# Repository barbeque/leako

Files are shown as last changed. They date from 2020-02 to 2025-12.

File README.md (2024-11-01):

The Leako logo

A ColecoVision-compatible games console that you can build yourself!

# License
The Leako project is licensed under [the Creative Commons Attribution-NonCommercial 4.0 license](https://creativecommons.org/licenses/by-nc/4.0/).

# Project Introduction
I originally developed this board in order to play some ColecoVision games that I had gotten from the flea market. This turned into several articles on my old-computer repair blog, Leaded Solder:

 - [Part 1](https://www.leadedsolder.com/2020/02/16/colecovision-diy-part-1.html), covering the impetus and design;
 - [Part 2](https://www.leadedsolder.com/2020/07/10/colecovision-diy-part-2.html), covering the assembly and debugging.
 - [Part 3](https://www.leadedsolder.com/2021/10/14/colecovision-diy-part-3.html), covering "digital" joysticks and the Hand Controller
 - [Part 4](https://www.leadedsolder.com/2021/10/26/colecovision-diy-part-4.html), partially covering "quadrature" joysticks such as the steering wheel and Roller Controller

If you enjoyed this project or if you're interested in contributing to future development, I would greatly appreciate a subscription to [the Leaded Solder Patreon](https://www.patreon.com/leadedsolder). The Patreon not only helps me afford to develop expensive projects like this one, but also includes behind-the-scenes posts and previews of upcoming articles.

# Building It Yourself
First, use a PCB fabrication shop such as JLCPCB or PCBWay to order a Gerber file. You can get those from [the Releases page](https://github.com/barbeque/leako/releases).

Stay tuned for a more involved assembly guide, but early adopters are welcome to assemble and test a board.

For the easiest build, you can install [the Interactive BOM Plugin](https://github.com/openscopeproject/InteractiveHtmlBom) and use KiCad to export it. This will give you a click-through visual BOM that makes it really easy to assemble the board. Future versions of this board will come with one of these files in the Release.

You'll want to consult the BOM PDF for the version of the Leako board you wish to assemble. The first truly "working" version was v0.6. I recommend getting [the Gerber ZIPs and BOM from the Releases page](https://github.com/barbeque/leako/releases).

Not all parts on the BOM (Bill of Materials) can be obtained new. Many components are salvaged and can be obtained from eBay or other Chinese-market surplus stores such as AliExpress. Because the sellers and availability are changing constantly, I unfortunately cannot recommend a specific vendor. I suggest ordering from multiple different sellers and building more Leakos with all the leftover parts :)

For a quicker checkout process, [I have constructed a Digi-Key "list"](https://www.digikey.ca/en/mylists/list/FZA1NMR795) which can help you add all of the "new" parts necessary quickly. 

Namely, you will need to find:
 - A TI TMS9918A/TMS9918ANL (_not_ TMS9118, TMS9119, TMS9929, or TMS9928) VDP;
 - A TI SN76489 sound chip;
 - A 27c512-compatible EPROM (a 27c256 may also work but has not been tested);
 - ColecoVision cartridge games;
 - A ColecoVision-compatible controller

Please note the Leako has, so far, only been constructed and tested in NTSC regions. A PAL version would be a very interesting conversion, but would use a chip like a TMS9919 as well as probably some other board changes.

You will also need a USB power supply and a USB-B cable. I recommend using a USB power supply capable of at least 2A - although I have only measured ~450mA max in practice, it would not be a bad idea to have some additional headroom. A lower-quality supply is also likely to introduce more noise. I have tested with two models of Anker PowerPort.

Please also note that at the time of publication, a silicon and fabrication shortage has meant that many parts (for instance, the TI TPS60403 -5V voltage inverter) have become difficult and/or more expensive to locate than when the machine was originally designed. Some have been substituted, but there are likely others.

## Tools
The ColecoVision games and console rely on the presence of a BIOS ROM. In order to program the EPROM with the BIOS, you'll need a copy of the BIOS (it can be dumped from a real ColecoVision) and an EPROM programmer such as a TL866II+.

For soldering surface-mount parts, I strongly recommend a good temperature-controlled soldering iron such as a Hakko FX-888, paste flux, and quality leaded solder from a brand like Kester or MG Chemical. You can use lead-free solder, but I haven't.

# Compatibility
If you have built your own Leako and tested it with a game that's not listed here, please submit a pull request to add it to this list.

| Game | Works? | Notes |
|---|---|---|
| Donkey Kong | Yes | |
| Zaxxon | Yes | |
| Time Pilot | Yes | |
| Carnival | Yes | |
| Frenzy | Yes | |
| Ken Uston's Black Jack / Poker | Yes | |
| Looping 	| Yes	 |	 |
| Omega Race	| Yes	 | Tested with Hand Controller |

| Peripheral | Works? | Notes |
|---|---|---|
| ColecoVision controller | Yes | |
| ADAM controller | Yes | |
| Super Action Controller | Yes | Tested with _Super Action Baseball_ only |
| Roller Controller | Partial | Tested with _Slither_ only; my controller is not working properly, even on a real ColecoVision |
| Expansion Module #2 (steering controller) | Partial | Tested with _Turbo_ only; my controller is not working properly, even on a real ColecoVision |

The latter two will be re-investigated as the controllers are tested, and hopefully this table will be updated with some better news in the future.

Please note:
 * The Leako board does not have a ColecoVision expansion connector, so it cannot work with any Expansion Modules, including the ADAM.
 * The Leako board does not have a ColecoVision power connector, so the Roller Controller will need to be powered independently using a ColecoVision power supply such as the ColUSB, or wired for a +5V source such as a USB cable.

# Known Issues
## "Always On" phenomenon
If you power the Leako off a monitor or television set that is also being used to display the Leako, it can complete the "ground" circuit from the USB jack through the composite video jack and keep the Leako turned on, bypassing the power switch entirely. In this scenario, the Leako will remain powered on, regardless of the power switch position.

To work around this problem, try powering the Leako from a different USB power source, or use a television that isolates USB ground from video ground.

Thank you to Cheshire Noir and Tom Storey for figuring this one out.

# Version History
## v0.8
More small fixes.
 * Move U20/U11 to other side of board so cartridges with extra long skirts or loose PCBs won't interfere with them.
 * Move mounting hole added in previous step to side of cartridge slot, so you don't have to use a low-profile screw head there anymore.
 * Larger pads on the 74LS574s, to ease soldering.
 * It is now much harder to hit the video filtering capacitor with the tip of a video cable.
 * Upgraded project files to KiCad 6

## v0.7
Many small fixes, mostly around reliability.
 * Correct missing junction from D3/D4 to R35 (EXT_QUAD pulldown.) Thank you to Oliver Fiero for catching this.
 * Unused logic inputs grounded to reduce power consumption.
 * Change controller ports from generic KiCad DE9 footprint to AE10968-ND
 * Change -5V charge pump because of parts shortage. Now ICL7660.
 * Controller port numbers on schematic now reflect actual logical controller ports.
 * Barrel jack 5V replaced with USB-B to broaden availability of high-quality regulated power supplies.
 * Additional mounting hole behind cartridge to reduce amount of board flex when cartridges are inserted and removed.
 * Thicker power traces.
 * Passives now labeled on board where possible, to speed assembly.

## v0.6
First working version.

# Links
 - [Console5 schematics and parts list](https://console5.com/wiki/Colecovision)
 - ChildOfCv's [better schematics](https://atariage.com/forums/topic/285656-new-colecovision-schematics/)
 - [Datasheet for LC331632M-12 SRAM](https://www.datasheet4u.com/datasheet-pdf/Sanyo/LC331632M-12/pdf.php?id=391797)
 - [Leonardo Miliani's SRAM video mod](https://www.leonardomiliani.com/en/2019/lm80c-tms9918a/)

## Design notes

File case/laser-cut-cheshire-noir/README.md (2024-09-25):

# Laser-cut case
By Cheshire Noir (thanks!)

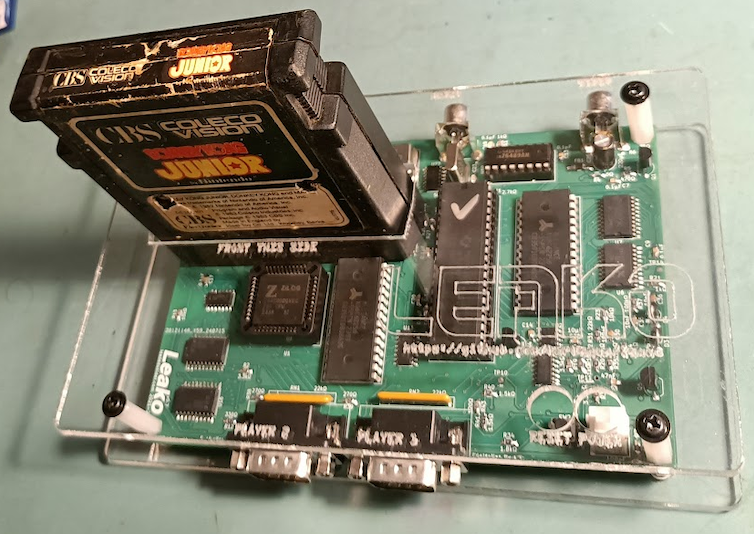
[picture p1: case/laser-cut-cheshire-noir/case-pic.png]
The case


## Other required parts
 - 5mm M3 nylon spacers
 - 20mm M3 nylon spacers

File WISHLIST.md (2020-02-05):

- [ ] Super Game Module support (32kB RAM, AY-3-8910A; remaps BIOS in memory space?)
- [ ] ADAM support (64kB RAM, ???; different decode logic for CV vs. ADAM mode?)
- [ ] Built-in flashcart BIOS with menu
- [ ] Portable variant (rearranged board) with LCD
- [ ] Backplane variant for easier testing/isolation
- [ ] Sega Genesis controller support (3 button + start instead of numpad)
- [ ] RGB output (requires TMS-9928)

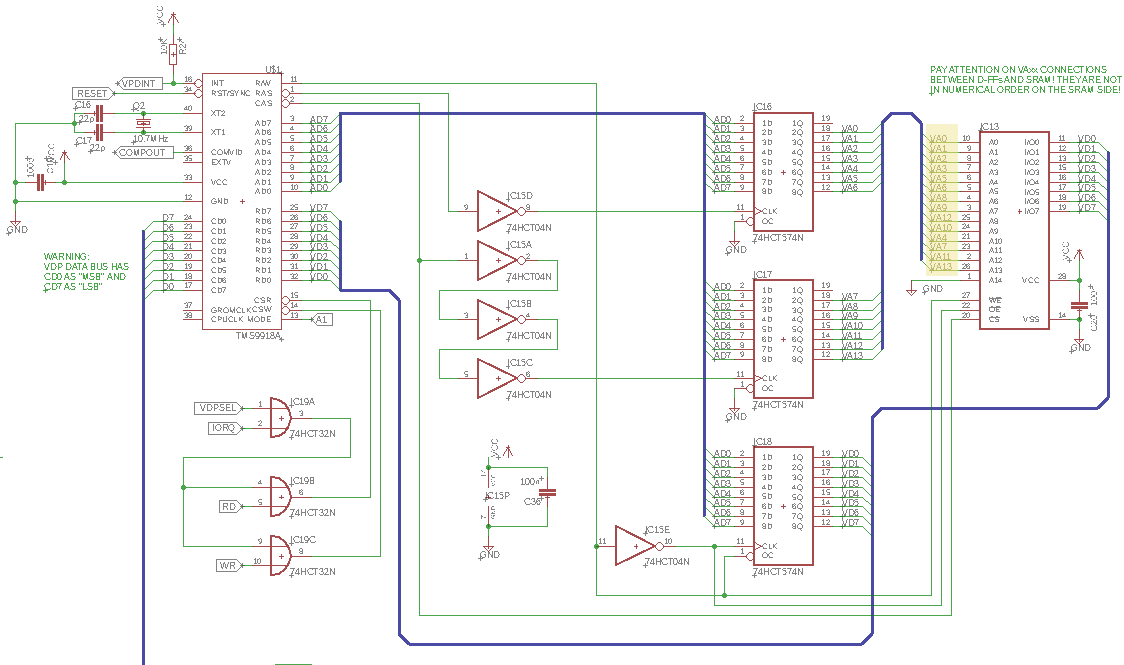
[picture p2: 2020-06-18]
References/leonardo tms9918 sram mod.png

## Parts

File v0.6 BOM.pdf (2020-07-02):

# Leako v0.6 BOM

Ref | Qnty | Value | Part | Footprint
C1, C2, C5, C6, C7, C8, C9, C13, C15, C16, C17, C18, C19, C20, C22, C24, C27, C29, C33, C34 | 20 | 0.1µF | Device:C | Capacitors_SMD:C_0805_HandSoldering
C3, C32 | 2 | 47nF | Device:C | Capacitors_SMD:C_0805_HandSoldering
C4 | 1 | 0.1µF | Device:CP1_Small | Capacitors_SMD:C_0805_HandSoldering
C10, C11 | 2 | 0.1µF | Device:C_Small | Capacitors_SMD:C_0805_HandSoldering
C12 | 1 | 22µF | Device:CP | Capacitors_ThroughHole:CP_Radial_D5.0mm_P2.50mm
C21, C39, C40, C41 | 4 | 1µF | Device:C | Capacitors_SMD:C_0805_HandSoldering
C23, C26 | 2 | 56pF | Device:C_Small | Capacitors_SMD:C_0805_HandSoldering
C25 | 1 | 220µF | Device:CP1_Small | Capacitors_ThroughHole:CP_Radial_D6.3mm_P2.50mm
C30, C31 | 2 | 100pF | Device:C | Capacitors_SMD:C_0805_HandSoldering
C35, C36, C37, C38 | 4 | 10nF | Device:C | Capacitors_SMD:C_0805_HandSoldering
D1 | 1 | LED | Device:LED | LEDs:LED_D3.0mm
D2 | 1 | 50V 2A | Device:D_Schottky | Diodes_ThroughHole:D_DO-15_P10.16mm_Horizontal
D3, D4 | 2 | 1N4001 | Diode:1N4001 | Diodes_ThroughHole:D_DO-41_SOD81_P2.54mm_Vertical_AnodeUp
F2 | 1 | 2A | Device:Fuse_Small | 0251002.MRT1L:0251002.MRT1L
FB1 | 1 | Bead | Device:Ferrite_Bead_Small | Choke_SMD:Choke_SMD_1206_Handsoldering
J1 | 1 | Cartridge Slot | Connector_Generic:Conn_02x15_Odd_Even | LeakyChips:Sullins_Cart_Slot
J2 | 1 | Composite video | RCJ-017:RCJ-017 | Jacks:CUI_RCJ-017
J3 | 1 | PJ-102A | PJ-102A:PJ-102A | Jacks:CUI_PJ-102A
J4 | 1 | RCJ-017 | RCJ-017:RCJ-017 | Jacks:CUI_RCJ-017
J5 | 1 | Controller Port 1 | Connector:DB9_Male | Connector_Dsub:DSUB-9_Male_Horizontal_P2.77x2.84mm_EdgePinOffset4.94mm_Housed_MountingHolesOffset7
J6 | 1 | Controller Port 2 | Connector:DB9_Male | Connector_Dsub:DSUB-9_Male_Horizontal_P2.77x2.84mm_EdgePinOffset4.94mm_Housed_MountingHolesOffset7
Q1 | 1 | 2n4401 | Device:Q_NPN_EBC | TO_SOT_Packages_THT:TO-92_Inline_Wide
Q2 | 1 | Q_NJFET_GSD | Device:Q_NJFET_GSD | TO_SOT_Packages_SMD:SOT-23_Handsoldering
Q4, Q5 | 2 | 2N3904 | Transistor_BJT:2N3904 | TO_SOT_Packages_THT:TO-92_Inline_Wide
R1, | 5 | 1kΩ | Device:R_Small_US | Resistors_SMD:R_0805_HandSoldering

R11, R18, R21, R28

R2, R3, R9, R10, R14, R19, R44 | 7 | 3.3kΩ | Device:R_Small_US | Resistors_SMD:R_0805_HandSoldering
R4 | 1 | 0Ω | Device:R_Small_US | Resistors_SMD:R_0805_HandSoldering
R5 | 1 | 470Ω | Device:R_Small_US | Resistors_SMD:R_0805_HandSoldering
R6 | 1 | 75Ω | Device:R_Small_US | Resistors_SMD:R_0805_HandSoldering
R7 | 1 | 150Ω | Device:R_Small_US | Resistors_SMD:R_0805_HandSoldering
R12 | 1 | 330Ω | Device:R_Small_US | Resistors_SMD:R_0805_HandSoldering
R13, R23, R24 | 3 | 10kΩ | Device:R_Small_US | Resistors_SMD:R_0805_HandSoldering
R15 | 1 | 4.7kΩ | Device:R_Small_US | Resistors_SMD:R_0805_HandSoldering
R16 | 1 | 91kΩ | Device:R_Small_US | Resistors_SMD:R_0805_HandSoldering
R17 | 1 | 1MΩ | Device:R_Small_US | Resistors_SMD:R_0805_HandSoldering
R20, R31, R32 | 3 | 22kΩ | Device:R_Small_US | Resistors_SMD:R_0805_HandSoldering
R27 | 1 | 47Ω | Device:R_Small_US | Resistors_SMD:R_0805_HandSoldering
R33, R34 | 2 | 1.8kΩ | Device:R_Small_US | Resistors_SMD:R_0805_HandSoldering
R35, R40, R41 | 3 | 1.5kΩ | Device:R_Small_US | Resistors_SMD:R_0805_HandSoldering
R36, R37 | 2 | 100kΩ | Device:R_Small_US | Resistors_SMD:R_0805_HandSoldering
R38, R39 | 2 | 270Ω | Device:R_Small_US | Resistors_SMD:R_0805_HandSoldering
R42, R43 | 2 | 120Ω | Device:R_Small_US | Resistors_SMD:R_0805_HandSoldering
RN1, RN2 | 2 | 22kΩ | Device:R_Network07_US | Resistors_ThroughHole:R_Array_SIP8
SW1 | 1 | Power Toggle | Switch:SW_Push | LeakyChips:PVA1_Switch
SW2 | 1 | Reset | Switch:SW_Push | Buttons_Switches_ThroughHole:SW_PUSH_6mm
U1 | 1 | PLCCZ80 | LeadedSolder:PLCCZ80 | Sockets:PLCC44
U3 | 1 | BIOS ROM 27C256 | Memory_EPROM:27C256 | Housings_DIP:DIP-28_W15.24mm_Socket_LongPads
U4 | 1 | 74HCT04 | 74xx:74HCT04 | Housings_SOIC:SOIC-14_3.9x8.7mm_Pitch1.27mm
U5 | 1 | TMS9918A | LeakoChips:TMS9918A | Housings_DIP:DIP-40_W15.24mm_Socket_LongPads
U6, U7, U8 | 3 | 74HCT574 | 74xx:74LS574 | Housings_SOIC:SOIC-20W_7.5x12.8mm_Pitch1.27mm
U10 | 1 | SN76489AN | LeakoChips:SN76489AN | Housings_DIP:DIP-16_W7.62mm_Socket_LongPads
U11 | 1 | 74LS04 | 74xx:74LS04 | Housings_SOIC:SOIC-14_3.9x8.7mm_Pitch1.27mm
U12 | 1 | 74LS138 (Mem. Mapped) | 74xx:74LS138 | Housings_SOIC:SOIC-16_3.9x9.9mm_Pitch1.27mm
U13 | 1 | 74LS138 (I/O) | 74xx:74LS138 | Housings_SOIC:SOIC-16_3.9x9.9mm_Pitch1.27mm
U14 | 1 | 74LS02 | 74xx:74LS02 | Housings_SOIC:SOIC-14_3.9x8.7mm_Pitch1.27mm
U15 | 1 | Controller 1 | 74xx_IEEE:74LS541 | Housings_SOIC:SOIC-20W_7.5x12.8mm_Pitch1.27mm
U16 | 1 | Controller 2 | 74xx_IEEE:74LS541 | Housings_SOIC:SOIC-20W_7.5x12.8mm_Pitch1.27mm
U17, U18 | 2 | 74LS05 | 74xx:74LS05 | Housings_SOIC:SOIC-14_3.9x8.7mm_Pitch1.27mm
U20, U22 | 2 | 74LS74 | 74xx:74LS74 | Housings_SOIC:SOIC-14_3.9x8.7mm_Pitch1.27mm
U23 | 1 | 74HCT00 | 74xx:74HCT00 | Housings_SOIC:SOIC-14_3.9x8.7mm_Pitch1.27mm
U24 | 1 | TPS60403DBVR | TPS60403DBVR:TPS60403DBVR | TO_SOT_Packages_SMD:SOT-23-5_HandSoldering
U100, | 2 | AS6C62256-DIP | AS6C62256:AS6C62256-DIP | Housings_DIP:DIP-28_W15.24mm_Socket_LongPads

U101

X1 | 1 | 14.31818MHz | Oscillator:CXO_DIP8 | Oscillators:Oscillator_DIP-8_LargePads
Y1 | 1 | 10.738635MHZ | Device:Crystal | Crystals:Crystal_HC49-U_Vertical

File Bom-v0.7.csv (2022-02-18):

Customer Reference | Component Name | Value | Footprint | Part Number | Quantity | Description
C1, C2, C4, C5, C6, C7, C8, C9, C10, C11, C13, C15, C16, C17, C18, C19, C20, C22, C24, C27, C29, C33, C34 | C | 0.1µF | Capacitors_SMD:C_0805_HandSoldering | 1276-1099-1-ND | 23 | Unpolarized capacitor
C3, C32 | C | 47nF | Capacitors_SMD:C_0805_HandSoldering | 732-8059-1-ND | 2 | Unpolarized capacitor
C12 | CP | 22µF | Capacitors_ThroughHole:CP_Radial_D5.0mm_P2.50mm | 493-1037-ND | 1 | Polarized capacitor
C14, C28 | C_Small | 10µF | Capacitor_SMD:C_0805_2012Metric_Pad1.15x1.40mm_HandSolder | 1276-1298-1-ND | 2 | Unpolarized capacitor, small symbol
C21 | C | 1µF | Capacitors_SMD:C_0805_HandSoldering | 1276-2926-1-ND | 1 | Unpolarized capacitor
C23, C26 | C_Small | 56pF | Capacitors_SMD:C_0805_HandSoldering | 732-7817-1-ND | 2 | Unpolarized capacitor, small symbol
C25 | CP1_Small | 220µF | Capacitors_ThroughHole:CP_Radial_D6.3mm_P2.50mm | 493-15121-ND | 1 | Polarized capacitor, small US symbol
C30, C31 | C | 100pF | Capacitors_SMD:C_0805_HandSoldering | 732-12161-1-ND | 2 | Unpolarized capacitor
C35, C36, C37, C38 | C | 10nF | Capacitors_SMD:C_0805_HandSoldering | 399-C0805X103K1RAC3316CT-ND | 4 | Unpolarized capacitor
D1 | LED | LED | LEDs:LED_D3.0mm | 1497-1022-ND | 1 | Light emitting diode
D3, D4 | 1N4001 | 1N4001 | Diodes_ThroughHole:D_DO-41_SOD81_P2.54mm_Vertical_AnodeUp | 641-1310-1-ND | 2 | 50V 1A General Purpose Rectifier Diode, DO-41
F2 | Fuse_Small | 2A | 0251002.MRT1L:0251002.MRT1L | F3171CT-ND | 1 | Fuse, small symbol
FB1 | Ferrite_Bead_Small | Bead | Choke_SMD:Choke_SMD_1206_Handsoldering | 283-MFBW1V3216-310-RCT-ND | 1 | Ferrite bead, small symbol
J1 | Conn_02x15_Odd_Even | Cartridge Slot | LeakyChips:Sullins_Cart_Slot | S3305-ND | 1 | Generic connector, double row, 02x15, odd/even pin numbering scheme (row 1 odd numbers, row 2 even numbers), script generated (kicad-library-utils/schlib/autogen/connector/)
J2 | RCJ-017 | Composite video | Jacks:CUI_RCJ-017 | CP-1403-ND‎ | 1
J3 | USB-B1HSB6 | USB-B1HSB6 | OST_USB-B1HSB6 | ED2982-ND | 1
J4 | RCJ-017 | RCJ-013 | Jacks:CUI_RCJ-017 | CP-1402-ND‎ | 1
J5 | DB9_Male | Controller Port 2 | Jacks:A-DS 09 A-KG-T2S | AE10968-ND | 1 | 9-pin male D-SUB connector
J6 | DB9_Male | Controller Port 1 | Jacks:A-DS 09 A-KG-T2S | AE10968-ND | 1 | 9-pin male D-SUB connector
Q1 | Q_NPN_EBC | 2n4401 | TO_SOT_Packages_THT:TO-92_Inline_Wide | 2N4401TFCT-ND | 1 | NPN transistor, emitter/base/collector
Q2 | Q_NJFET_GSD | Q_NJFET_GSD | TO_SOT_Packages_SMD:SOT-23_Handsoldering | DMN6075S-7DICT-ND | 1 | N-JFET transistor, gate/source/drain
Q4, Q5 | 2N3904 | 2N3904 | TO_SOT_Packages_THT:TO-92_Inline_Wide | 2N3904TAFSCT-ND | 2 | 0.2A Ic, 40V Vce, Small Signal NPN Transistor, TO-92
R1 | R_Small_US | 2.7kΩ | Resistors_SMD:R_0805_HandSoldering | RMCF0805JT2K70CT-ND | 1 | Resistor, small US symbol
R2, R3, R9, R10, R14, R19, R44 | R_Small_US | 3.3kΩ | Resistors_SMD:R_0805_HandSoldering | RMCF0805JT3K30CT-ND | 7 | Resistor, small US symbol
R4 | R_Small_US | 0Ω | Resistors_SMD:R_0805_HandSoldering | RMCF0805ZT0R00CT-ND | 1 | Resistor, small US symbol
R5 | R_Small_US | 470Ω | Resistors_SMD:R_0805_HandSoldering | RMCF0805JT470RCT-ND | 1 | Resistor, small US symbol
R6 | R_Small_US | 75Ω | Resistors_SMD:R_0805_HandSoldering | RMCF0805JT75R0CT-ND | 1 | Resistor, small US symbol
R7 | R_Small_US | 150Ω | Resistors_SMD:R_0805_HandSoldering | RMCF0805JT150RCT-ND | 1 | Resistor, small US symbol
R11, R18, R21, R28 | R_Small_US | 1kΩ | Resistors_SMD:R_0805_HandSoldering | RMCF0805FT1K00CT-ND | 4 | Resistor, small US symbol
R12 | R_Small_US | 330Ω | Resistors_SMD:R_0805_HandSoldering | RMCF0805JT330RCT-ND | 1 | Resistor, small US symbol
R13, R23, R24 | R_Small_US | 10kΩ | Resistors_SMD:R_0805_HandSoldering | RMCF0805JT10K0CT-ND | 3 | Resistor, small US symbol
R15 | R_Small_US | 4.7kΩ | Resistors_SMD:R_0805_HandSoldering | RMCF0805JT4K70CT-ND | 1 | Resistor, small US symbol
R16 | R_Small_US | 91kΩ | Resistors_SMD:R_0805_HandSoldering | RMCF0805JT91K0CT-ND | 1 | Resistor, small US symbol
R17 | R_Small_US | 1MΩ | Resistors_SMD:R_0805_HandSoldering | RMCF0805JT1M00CT-ND | 1 | Resistor, small US symbol
R20, R31, R32 | R_Small_US | 22kΩ | Resistors_SMD:R_0805_HandSoldering | RMCF0805JT22K0CT-ND | 3 | Resistor, small US symbol
R27 | R_Small_US | 47Ω | Resistors_SMD:R_0805_HandSoldering | RMCF0805JT47R0CT-ND | 1 | Resistor, small US symbol
R33, R34 | R_Small_US | 1.8kΩ | Resistors_SMD:R_0805_HandSoldering | RMCF0805JT1K80CT-ND | 2 | Resistor, small US symbol
R35, R40, R41 | R_Small_US | 1.5kΩ | Resistors_SMD:R_0805_HandSoldering | RMCF0805JT1K50CT-ND | 3 | Resistor, small US symbol
R36, R37 | R_Small_US | 100kΩ | Resistors_SMD:R_0805_HandSoldering | RMCF0805JT100KCT-ND | 2 | Resistor, small US symbol
R38, R39 | R_Small_US | 270Ω | Resistors_SMD:R_0805_HandSoldering | RMCF0805JT270RCT-ND | 2 | Resistor, small US symbol
R42, R43 | R_Small_US | 120Ω | Resistors_SMD:R_0805_HandSoldering | RMCF0805JT120RCT-ND | 2 | Resistor, small US symbol
RN1, RN2 | R_Network07_US | 22kΩ | Resistors_ThroughHole:R_Array_SIP8 | 4608X-1-223LF-ND | 2 | 7 resistor network, star topology, bussed resistors, small US symbol
SW1 | SW_Push | Power Toggle | LeakyChips:PVA1_Switch | 401-1132-ND | 1 | Push button switch, generic, two pins
SW2 | SW_Push | Reset | Buttons_Switches_ThroughHole:SW_PUSH_6mm | 679-2428-ND | 1 | Push button switch, generic, two pins
TP2, TP3, TP11 | TestPoint | TestPoint | Measurement_Points:Measurement_Point_Round-TH_Small |  | 3 | test point
TP10 | TestPoint | -5V | Measurement_Points:Measurement_Point_Round-SMD-Pad_Small |  | 1 | test point
TP14 | TestPoint | TestPoint | Measurement_Points:Measurement_Point_Round-SMD-Pad_Small |  | 1 | test point
U1 | PLCCZ80 | PLCCZ80 | Sockets:PLCC44 | 2057-PLCC-44-AT-ND | 1 | The PLCC variant of the Zilog Z80
U1 | PLCCZ80 | PLCCZ80 | Sockets:PLCC44 | 269-3899-ND | 1 | The PLCC variant of the Zilog Z80
U2 | ICL7660 | ICL7660 | Package_SO:SOIC-8_3.9x4.9mm_P1.27mm | ICL7660CSA+TCT-ND | 1 | Switched-Capacitor Voltage Converter, 1.5V to 10.0V operating supply voltage, 10mA with a 0.5V output drop, SO-8/DIP-8/µMAX-8/TO-99
U3 | 27C256 | BIOS ROM 27C256 | Housings_DIP:DIP-28_W15.24mm_Socket_LongPads | 2057-ICS-628-T-ND | 1 | OTP EPROM 256 KiBit
U4, U11 | 74LS04 | 74HCT04 | Housings_SOIC:SOIC-14_3.9x8.7mm_Pitch1.27mm | 296-31832-1-ND | 2 | Hex Inverter
U5 | TMS9918A | TMS9918A | Housings_DIP:DIP-40_W15.24mm_Socket_LongPads | ED3048-5-ND | 1
U6, U7, U8 | 74LS574 | 74HCT574 | Housings_SOIC:SOIC-20W_7.5x12.8mm_Pitch1.27mm | 1727-2856-1-ND | 3 | 8-bit Register, 3-state outputs
U10 | SN76489AN | SN76489AN | Housings_DIP:DIP-16_W7.62mm_Socket_LongPads | AE9992-ND | 1
U12 | 74LS138 | 74LS138 (Mem. Mapped) | Housings_SOIC:SOIC-16_3.9x9.9mm_Pitch1.27mm | 296-14883-2-ND | 1 | Decoder 3 to 8 active low outputs
U13 | 74LS138 | 74LS138 (I/O) | Housings_SOIC:SOIC-16_3.9x9.9mm_Pitch1.27mm | 296-14883-2-ND | 1 | Decoder 3 to 8 active low outputs
U14 | 74LS02 | 74LS02 | Housings_SOIC:SOIC-14_3.9x8.7mm_Pitch1.27mm | 296-14874-1-ND | 1 | quad 2-input NOR gate
U15 | 74LS541 | 74LS541 (Ctrl. 2) | Package_SO:SOIC-20W_7.5x12.8mm_P1.27mm | 296-14870-1-ND | 1 | 8-bit Buffer/Line Driver 3-state outputs
U16 | 74LS541 | 74LS541 (Ctrl. 1) | Package_SO:SOIC-20W_7.5x12.8mm_P1.27mm | 296-14870-1-ND | 1 | 8-bit Buffer/Line Driver 3-state outputs
U17, U18 | 74LS05 | 74LS05 | Housings_SOIC:SOIC-14_3.9x8.7mm_Pitch1.27mm | 296-1630-1-ND | 2 | Inverter Open Collect
U20, U22 | 74LS74 | 74LS74 | Housings_SOIC:SOIC-14_3.9x8.7mm_Pitch1.27mm | 296-14899-1-ND | 2 | Dual D Flip-flop, Set & Reset
U23 | 74HCT00 | 74HCT00 | Housings_SOIC:SOIC-14_3.9x8.7mm_Pitch1.27mm | 296-14542-1-ND | 1 | quad 2-input NAND gate
U100, U101 | AS6C62256-DIP | AS6C62256-DIP | Housings_DIP:DIP-28_W15.24mm_Socket_LongPads | 1450-1033-ND | 2
X1 | CXO_DIP8 | 14.31818MHz | Oscillators:Oscillator_DIP-8_LargePads | 535-9170-5-ND | 1 | Crystal Clock Oscillator, DIP8-style metal package
Y1 | Crystal | 10.738635MHZ | Crystals:Crystal_HC49-U_Vertical | CTX1443-ND | 1 | Two pin crystal

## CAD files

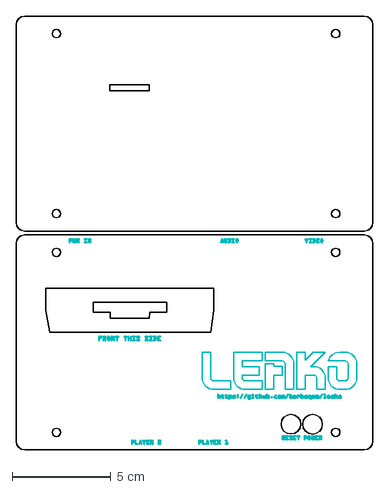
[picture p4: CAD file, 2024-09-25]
case/laser-cut-cheshire-noir/LeakoCase.dxf
18.1 x 22.0 cm

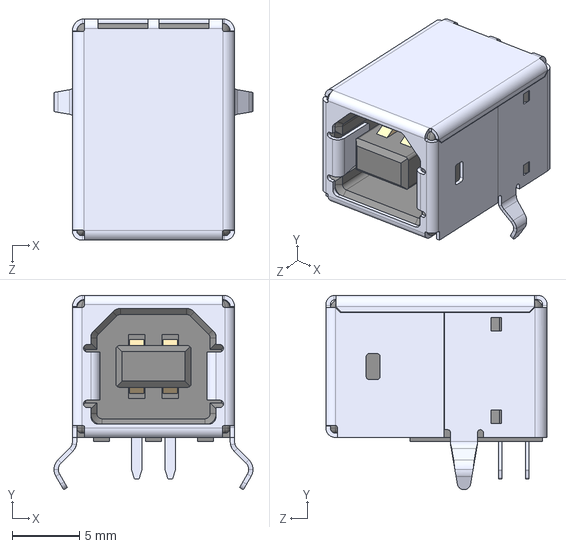
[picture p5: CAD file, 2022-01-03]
USB-B1HSB6/USB-B1HSB6.step
14.8 x 14.5 x 16.5 mm

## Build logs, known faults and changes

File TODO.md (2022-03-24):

- [x] figure out if i can use the LC331632M-12 (32k words * 16 bits) sram left over from the x'eye project - should work
- [x] figure out what the _other_ RAM was from the x'eye project - was it DRAM?
- [x] set up the SRAM-adapter for the TMS-9918 from the PDF - it's simple
- [x] figure out if I can use any of the ROMs i already have - yes, a 27c256 is more than enough
- [x] how does the original decode logic work with so few chips?
- [x] can i use one sanyo 16-bit ram for both the vdp and z80 since it has individual byte enables? NO
- [x] check the footprint against a real TMS9918 (print it out sooner rather than later)
- [x] can I use a knockoff U2413 as an AY-3-8910 to save some board room? are they that deeply compatible? i guess i already own an AY-3-8910. NEVER MIND IT'S AN SN76489 - already on order
- [x] video amp? used the one from the PDF
- [x] audio amp? is this too much gain? don't need one at all probably
- [x] reset circuit
- [x] cpu clock circuit ?????????????????? good enough for now?
- [x] how is the TMS clocked?
- [x] do i need to reverse a7..a0 for the TMS, or is that for data, or not at all?
- [x] what does RD in the SRAM-as-VRAM schematic do? they wouldn't have an extra inverter stage for nothing.
- [x] figure out memory decode
- [x] figure out IO decode
- [x] figure out cart decode (a subset of memory decode - bank switching)
- [x] what even are controllers?
- [x] add a bios rom
- [x] put in the keep-out zone for the cartridge slot (81mm x 40mm)
- [x] ram wraparound?
- [x] BIOS: what is up with the separate CE and OE in the original schematic (CE from A11?) Figure it out!!!
- [x] Expansion stubs (EXT_DEC_STUB, EXT_IO_STUB) need pullups or they'll fuck up
- [x] (CRITICAL) what is up with the -5V on the controller schematic?
- [x] fet to protect the power switch?
- [x] rca jacks around the right way?
- [x] why are the two 541s on the controller featuring different data bus pinouts?
- [x] map out the 541s
- [x] find some board spacers or a project case to lift this thing off a desk now that it's two sided
- [x] power U14, the ugly NOR that was used for the RAM
- [x] break out the remainder of the pins so i can use them as an inverter if need be
- [x] is it OK to tie CPU reset and VDP reset together? it is not
- [x] U21 feels unnecessary, we can probably drop it if we have leftover room on U14 in the end
- [x] find a replacement for the 7.15909MHz crystal (figure out how to divide a 14.31818)
- [x] you know what, can i just axe this entire clock section and use a 14mhz oscillator chip
- [x] replace the n/o jumpers with smd ones
- [x] size the power supply; can i get by with a 5V 2A switcher or will the voltage drop ruin it
- [x] power regulation - should i still have it if i have a 5V 2A switching supply?
- [x] replace the inline diode with a shunt to ground - rearrange the diode and fuse
- [x] is the SMD polyfuse on the load too small? yes, it's gone
- [x] weird flipflop-y section of the controller area with -5v
- [x] U21 (74hc04) seems not well used, lots of empty pins there
- [ ] U22 (flipflop) not well used either
- [ ] U18 (74ls05) is only half used
- [x] CRITICAL: undo the 100pF that i converted to 0.1uF on the real board (C26, C30, C31)
- [x] rotate the power switch
- [x] print out a bom for the v0.2 tag
- [x] abandon sanyo psram for 62256
# V0.7
- [ ] jumpers to potentially enable high address pins in ram (shh!)
- [ ] jumper to bypass capacitor on composite output
- [ ] jumper to switch -5V super pulldown to ground
- [x] controller port numbers flipped
- [x] unused inputs of u17 (ls05) should be grounded
- [x] unused inputs of u11 (ls04) should be grounded
- [ ] u17 and u18 should probably be merged, both are ls05s and barely used
- [ ] can u11 and u17 be merged and u11 dropped?
- [x] TI -5v regulator no longer available, use ICL7220?
- [x] bracing hole near cartridge
- [ ] ~~use the footprint of the de9 connector that i have, so it can be bolted (AMPHENOL 617-A009P-AJ121)~~
- [x] change the BOM to use a better de9 connector, possibly the one the footprint is based on (maybe AE10968-ND?)
- [x] convert power jack to USB
- [x] finish "making visible" all the hidden cap/resistor values
- [x] nice rounded edge on PCB (safety first)
# V0.8
- [x] move the mounting hole so it doesn't interfere with the cart shell when cart is loaded and screw is installed
- [ ] is the 10.7...mhz crystal making better video with 33pF or 56pF?
- [x] make 574s easier to place/solder with bigger pads

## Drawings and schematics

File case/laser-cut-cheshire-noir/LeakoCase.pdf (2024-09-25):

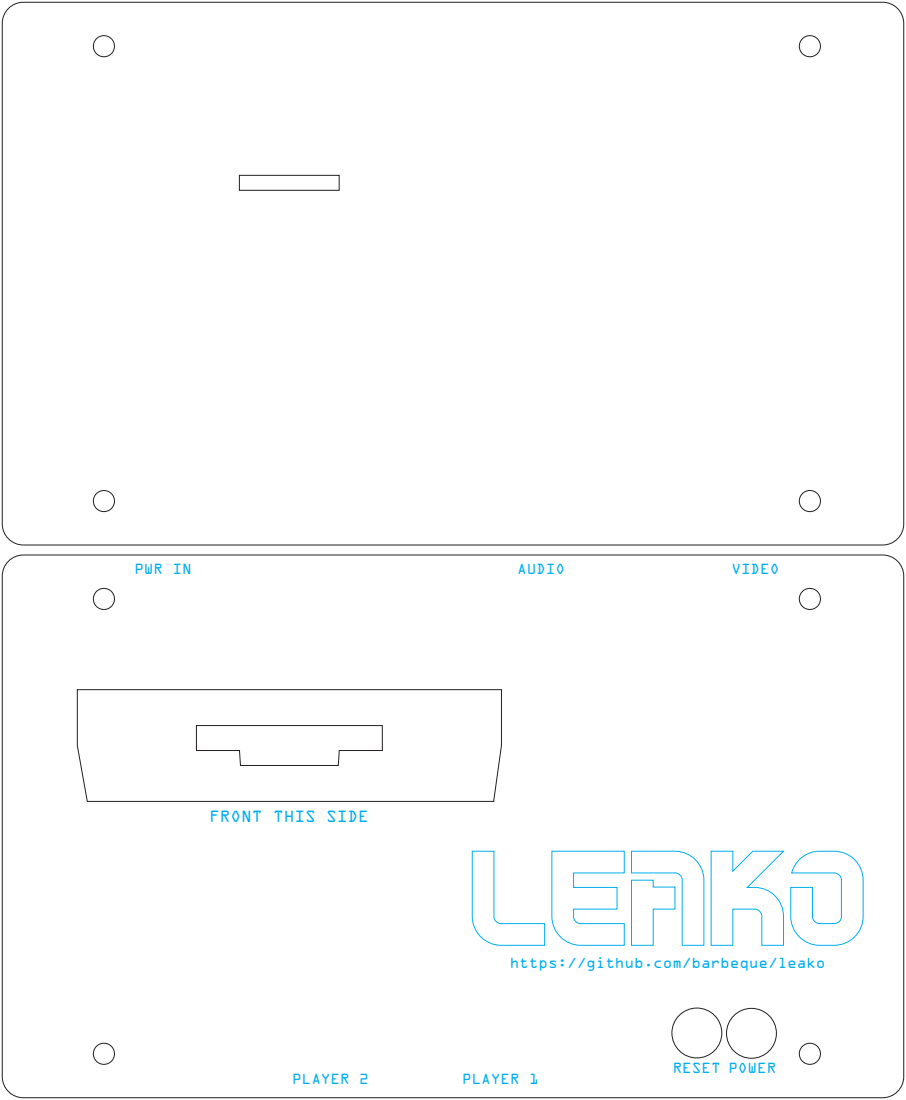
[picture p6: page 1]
RESET POWER; PWR IN; AUDIO; VIDEO; PLAYER 2; PLAYER 1

FRONT THIS SIDE

https://github.com/barbeque/leako

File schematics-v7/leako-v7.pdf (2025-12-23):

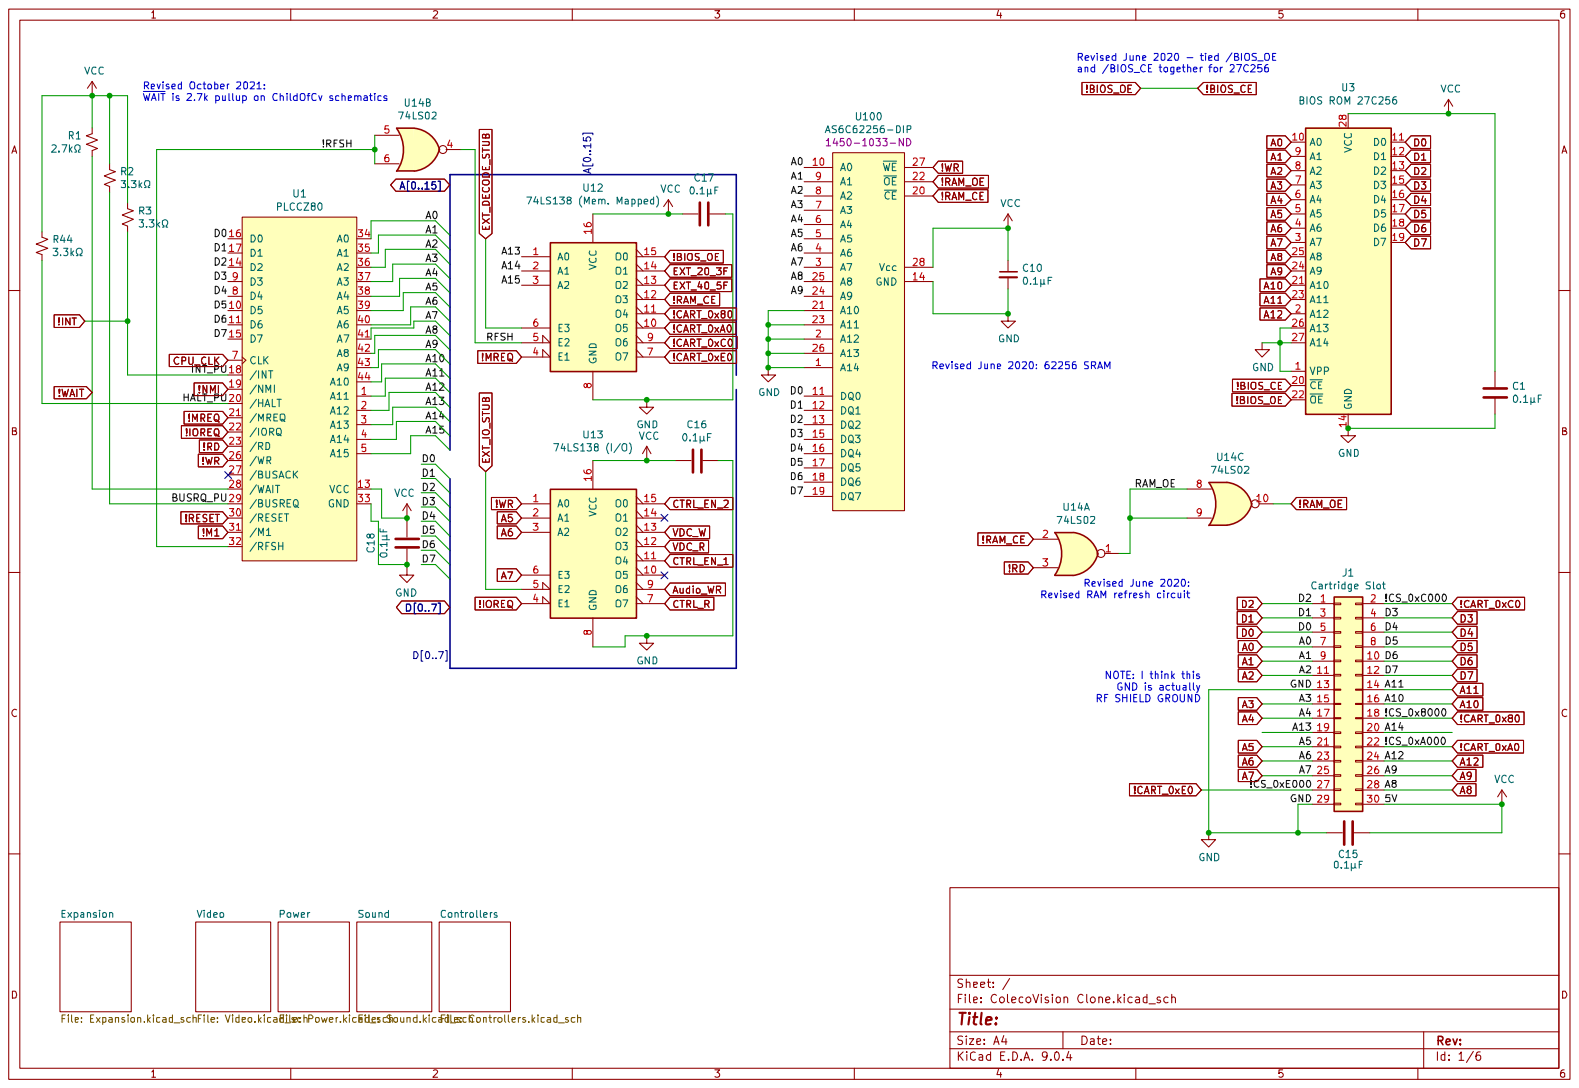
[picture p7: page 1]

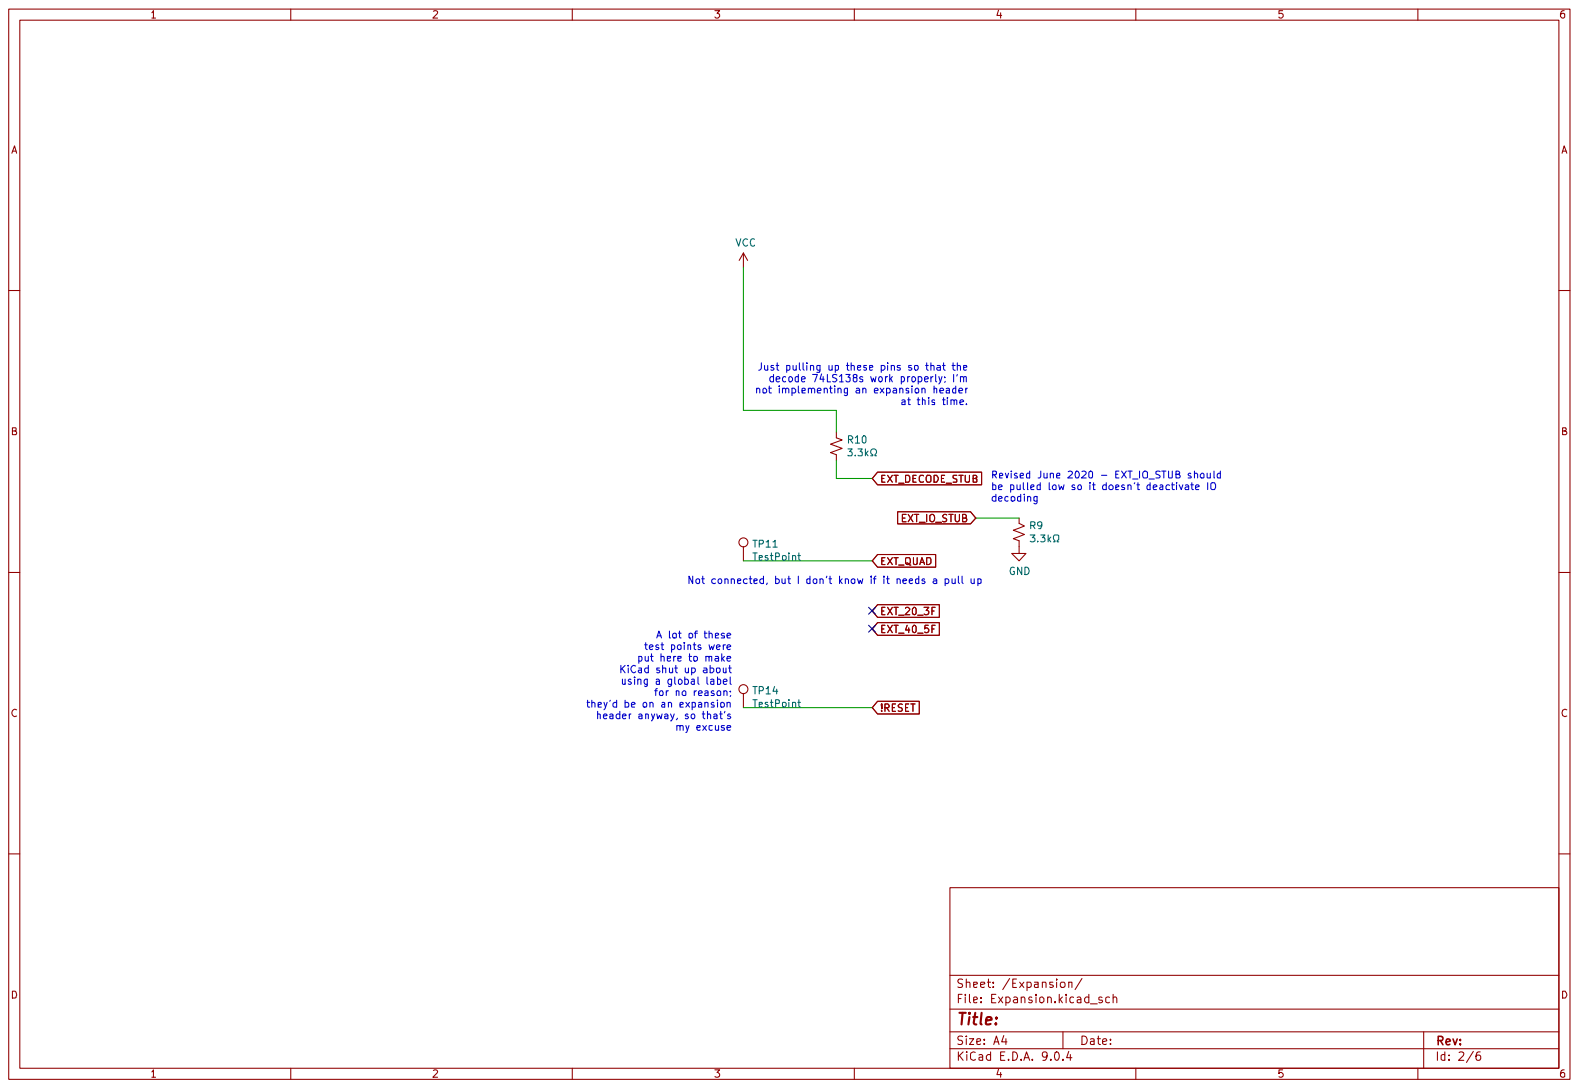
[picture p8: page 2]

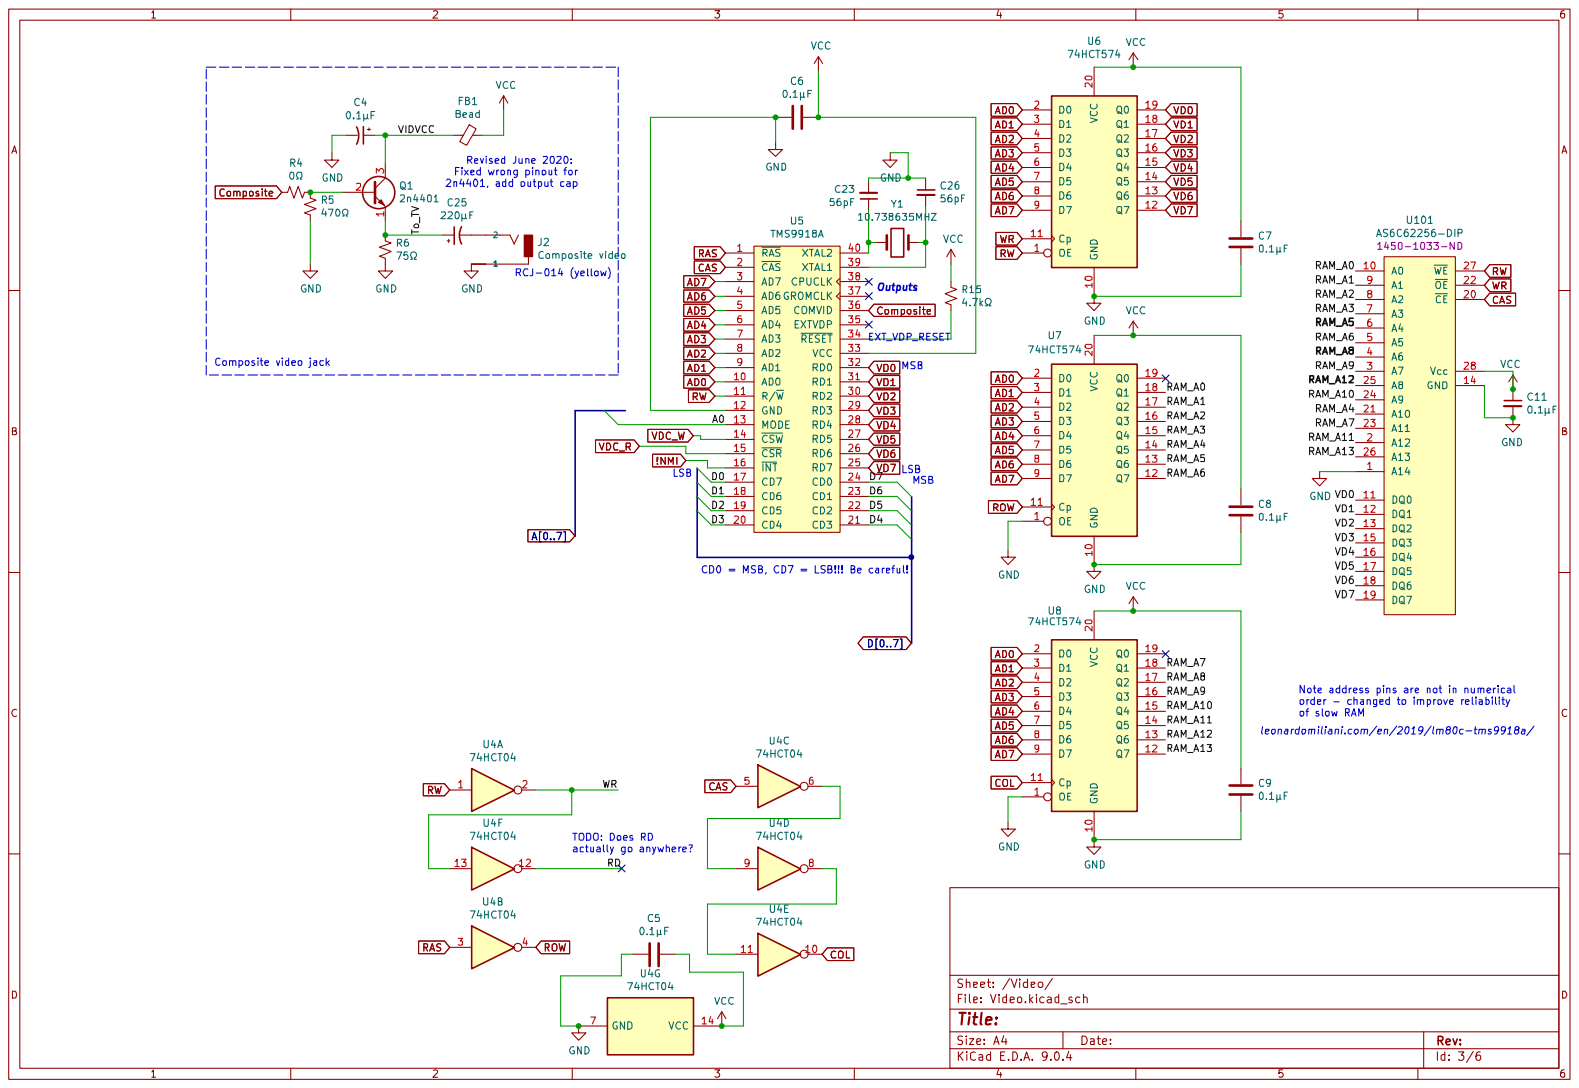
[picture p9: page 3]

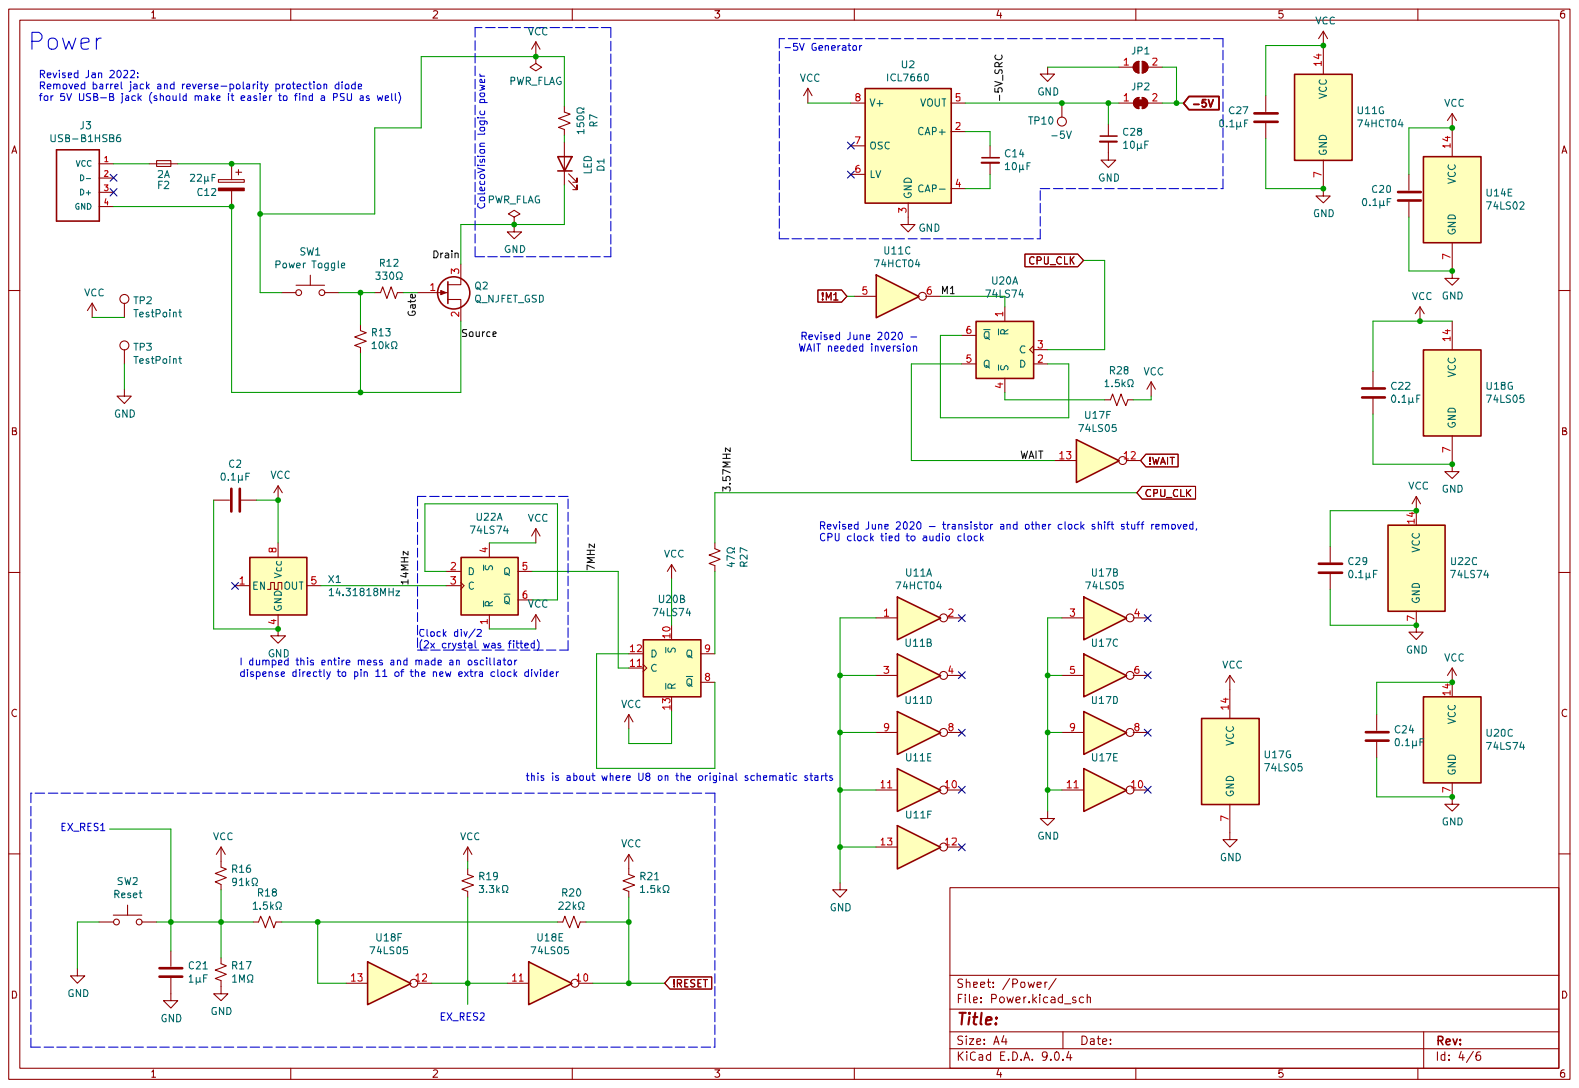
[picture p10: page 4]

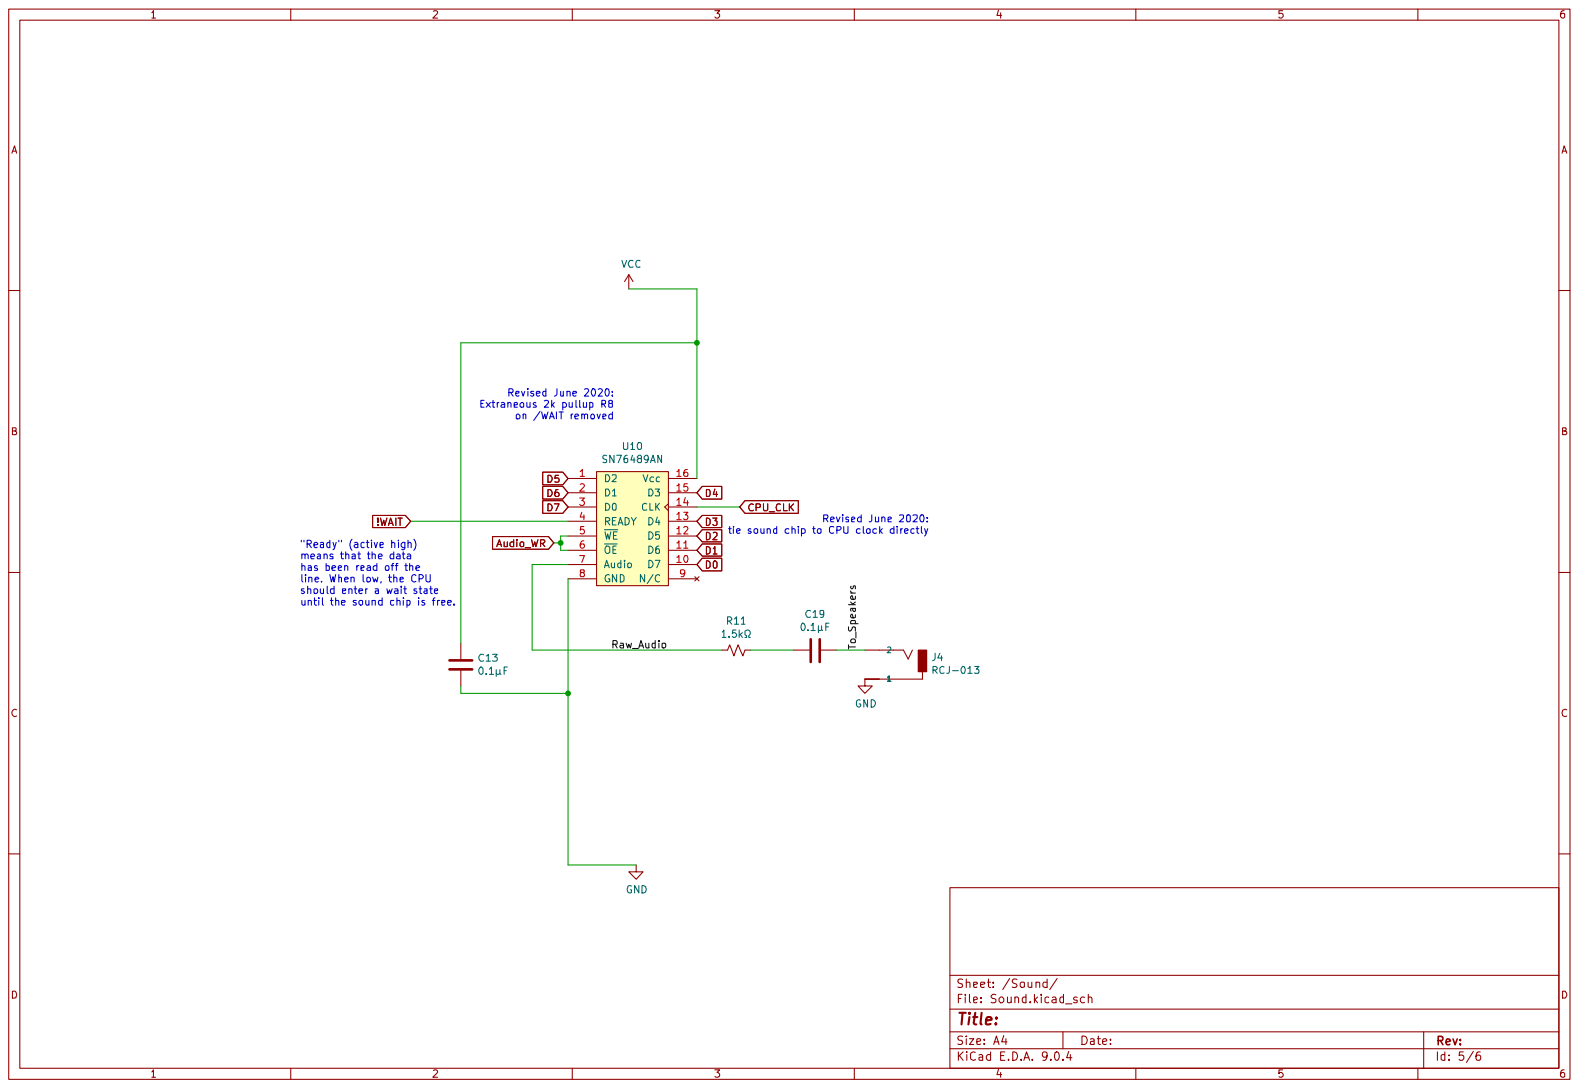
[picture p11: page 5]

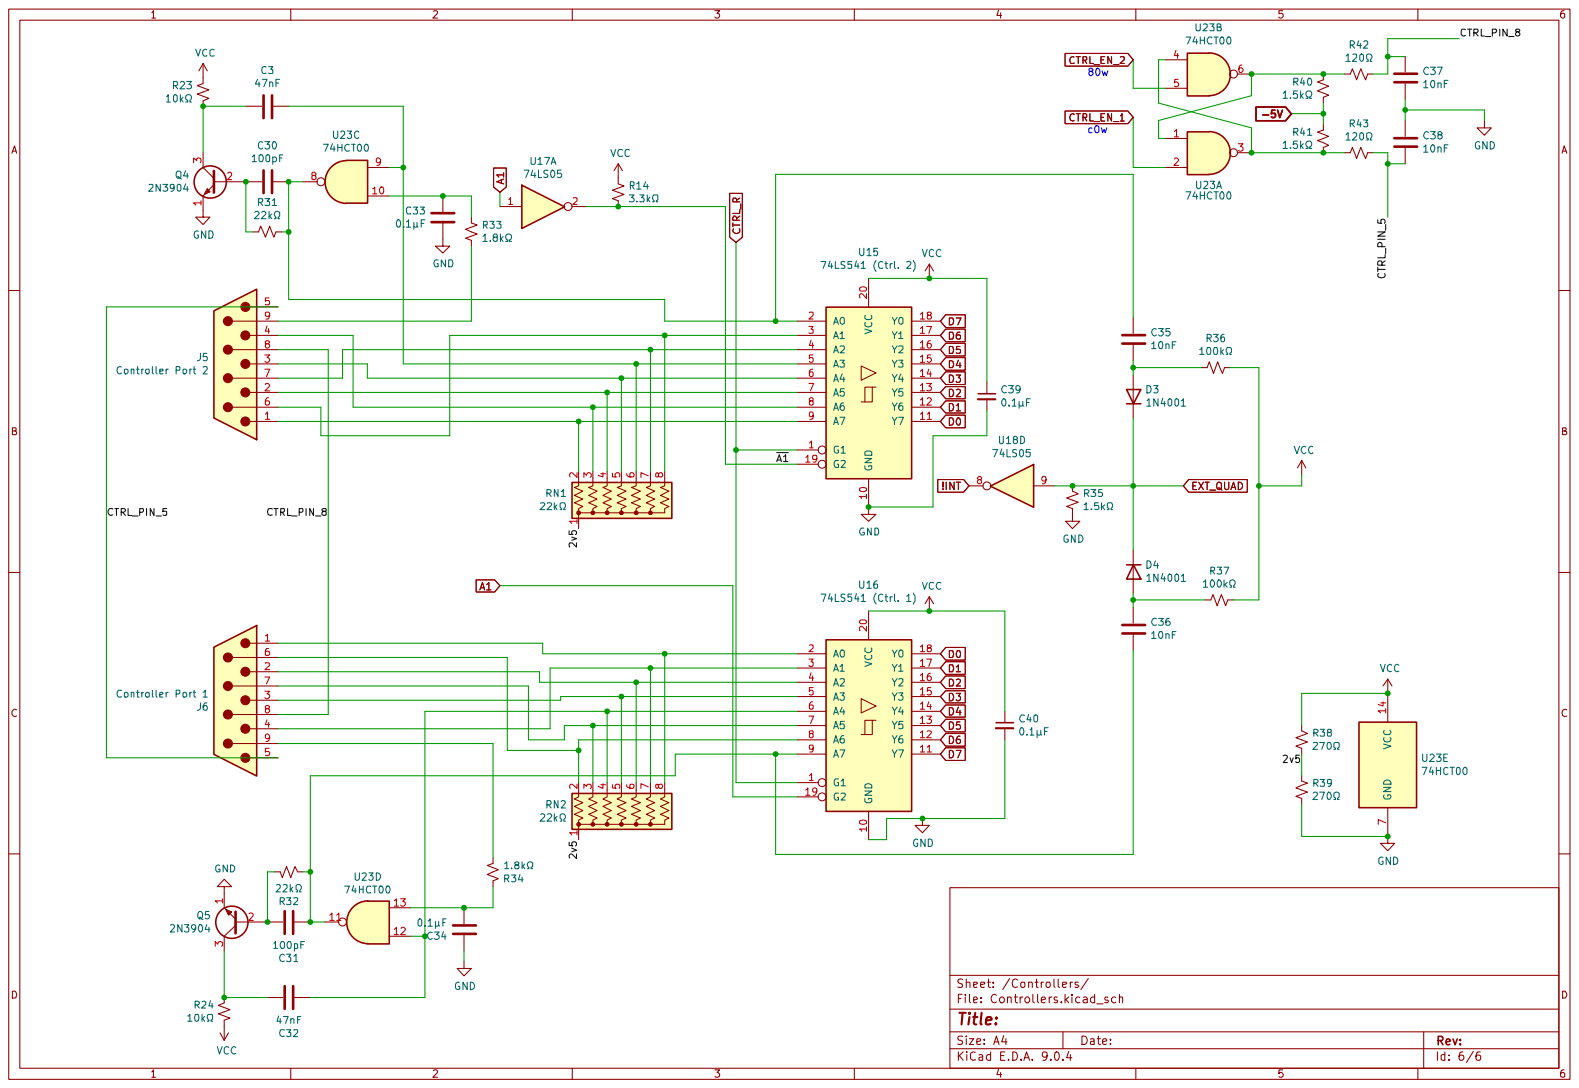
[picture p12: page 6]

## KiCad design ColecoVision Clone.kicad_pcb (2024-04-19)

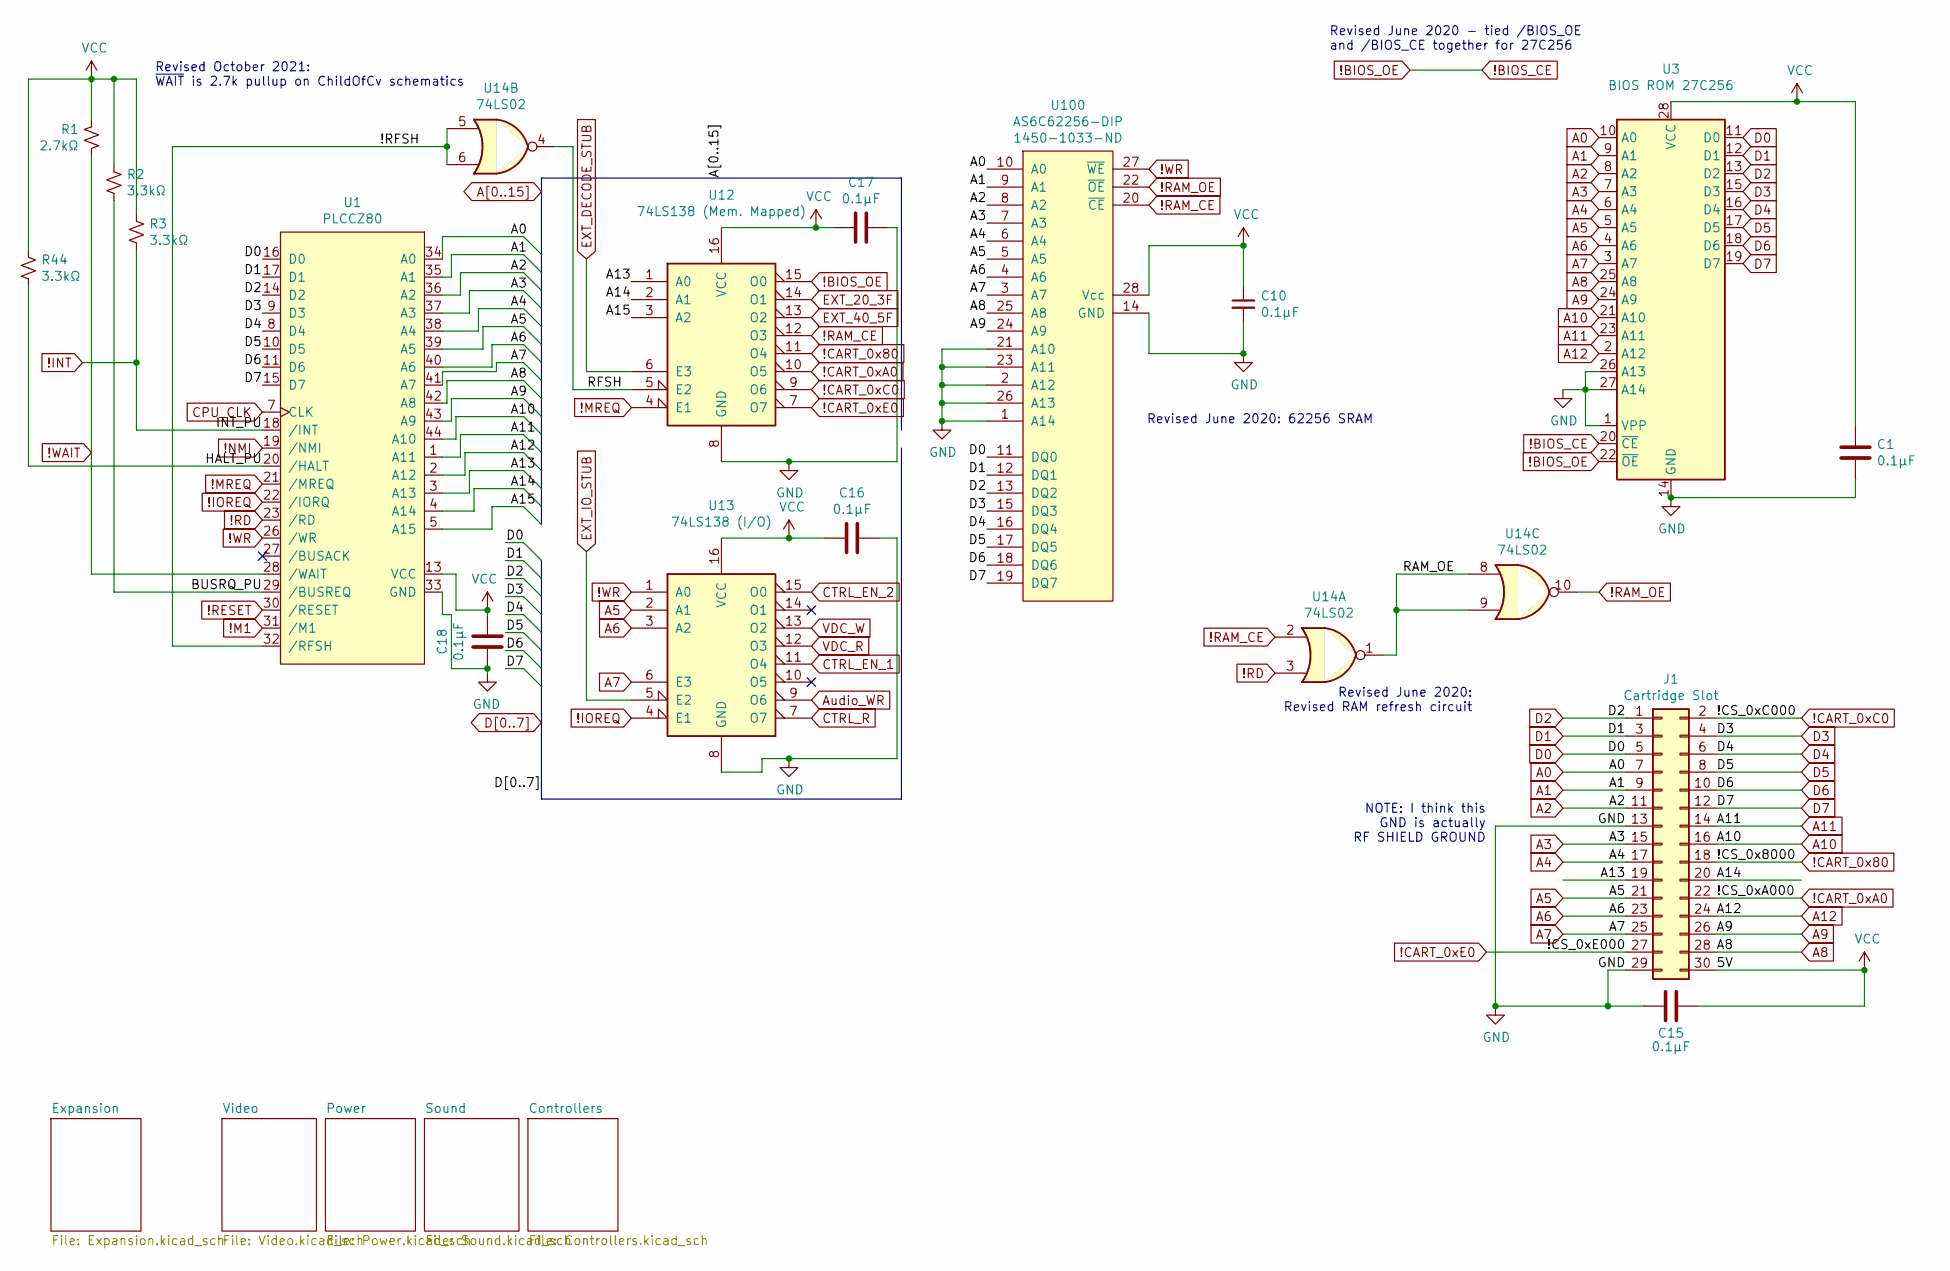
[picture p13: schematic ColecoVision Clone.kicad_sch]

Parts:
C1, C10, C15, C16, C17, C18: 0.1µF; C_0805_HandSoldering; DigiKey 1276-1099-1-ND
J1: Cartridge Slot; Sullins_Cart_Slot; DigiKey A31715-ND
R1: 2.7kΩ; R_0805_HandSoldering; DigiKey RMCF0805JT2K70CT-ND
R2, R3, R44: 3.3kΩ; R_0805_HandSoldering; DigiKey RMCF0805JT3K30CT-ND
U1: PLCCZ80; PLCC44; DigiKey 2057-PLCC-44-AT-ND; 269-3899-ND
U3: BIOS ROM 27C256; DIP-28_W15.24mm_Socket_LongPads; DigiKey 2057-ICS-628-T-ND
U12: 74LS138 (Mem. Mapped); SOIC-16_3.9x9.9mm_Pitch1.27mm; DigiKey 296-14883-2-ND
U13: 74LS138 (I/O); SOIC-16_3.9x9.9mm_Pitch1.27mm; DigiKey 296-14883-2-ND
U14: 74LS02; SOIC-14_3.9x8.7mm_Pitch1.27mm; DigiKey 296-14874-1-ND
U100: AS6C62256-DIP; DIP-28_W15.24mm_Socket_LongPads; DigiKey 1450-1033-ND

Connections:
!BIOS_CE: U3.20 (~CE), U3.22 (~OE), U12.15 (O0)
!CART_0x80: J1.18, U12.11 (O4)
!CART_0xA0: J1.22, U12.10 (O5)
!CART_0xC0: J1.2, U12.9 (O6)
!CART_0xE0: J1.27, U12.7 (O7)
!INT: R3.2, U1.18 (/INT); also elsewhere on the board
!IOREQ: U1.22 (/IORQ), U13.4 (E1)
!M1: U1.31 (/M1); also elsewhere on the board
!MREQ: U1.21 (/MREQ), U12.4 (E1)
!NMI: U1.19 (/NMI); also elsewhere on the board
!RAM_CE: U12.12 (O3), U14.2, U100.20 (~CE)
!RAM_OE: U14.10, U100.22 (~OE)
!RD: U1.23 (/RD), U14.3
!RESET: U1.30 (/RESET); also elsewhere on the board
!WAIT: R1.2, U1.28 (/WAIT); also elsewhere on the board
!WR: U1.26 (/WR), U13.1 (A0), U100.27 (~WE)
/!RFSH: U1.32 (/RFSH), U14.5, U14.6
/BUSRQ_PU: R2.2, U1.29 (/BUSREQ)
/HALT_PU: R44.2, U1.20 (/HALT)
/RAM_OE: U14.1, U14.8, U14.9
/RFSH: U12.5 (E2), U14.4
A0: J1.7, U1.34 (A0), U3.10 (A0), U100.10 (A0); also elsewhere on the board
A1: J1.9, U1.35 (A1), U3.9 (A1), U100.9 (A1); also elsewhere on the board
A2: J1.11, U1.36 (A2), U3.8 (A2), U100.8 (A2)
A3: J1.15, U1.37 (A3), U3.7 (A3), U100.7 (A3)
A4: J1.17, U1.38 (A4), U3.6 (A4), U100.6 (A4)
A5: J1.21, U1.39 (A5), U3.5 (A5), U13.2 (A1), U100.5 (A5)
A6: J1.23, U1.40 (A6), U3.4 (A6), U13.3 (A2), U100.4 (A6)
A7: J1.25, U1.41 (A7), U3.3 (A7), U13.6 (E3), U100.3 (A7)
A8: J1.28, U1.42 (A8), U3.25 (A8), U100.25 (A8)
A9: J1.26, U1.43 (A9), U3.24 (A9), U100.24 (A9)
A10: J1.16, U1.44 (A10), U3.21 (A10)
A11: J1.14, U1.1 (A11), U3.23 (A11)
A12: J1.24, U1.2 (A12), U3.2 (A12)
A13: J1.19, U1.3 (A13), U12.1 (A0)
A14: J1.20, U1.4 (A14), U12.2 (A1)
A15: U1.5 (A15), U12.3 (A2)
Audio_WR: U13.9 (O6); also elsewhere on the board
CPU_CLK: U1.7 (CLK); also elsewhere on the board
CTRL_EN_1: U13.11 (O4); also elsewhere on the board
CTRL_EN_2: U13.15 (O0); also elsewhere on the board
CTRL_R: U13.7 (O7); also elsewhere on the board
D0: J1.5, U1.16 (D0), U3.11 (D0), U100.11 (DQ0); also elsewhere on the board
D1: J1.3, U1.17 (D1), U3.12 (D1), U100.12 (DQ1); also elsewhere on the board
D2: J1.1, U1.14 (D2), U3.13 (D2), U100.13 (DQ2); also elsewhere on the board
D3: J1.4, U1.9 (D3), U3.15 (D3), U100.15 (DQ3); also elsewhere on the board
D4: J1.6, U1.8 (D4), U3.16 (D4), U100.16 (DQ4); also elsewhere on the board
D5: J1.8, U1.10 (D5), U3.17 (D5), U100.17 (DQ5); also elsewhere on the board
D6: J1.10, U1.11 (D6), U3.18 (D6), U100.18 (DQ6); also elsewhere on the board
D7: J1.12, U1.15 (D7), U3.19 (D7), U100.19 (DQ7); also elsewhere on the board
EXT_20_3F: U12.14 (O1)
EXT_40_5F: U12.13 (O2)
EXT_DECODE_STUB: U12.6 (E3); also elsewhere on the board
EXT_IO_STUB: U13.5 (E2); also elsewhere on the board
GND: C1.2, C10.2, C15.2, C16.1, C17.2, C18.1, J1.13, J1.29, U1.33 (GND), U3.1 (VPP), U3.14 (GND), U3.26 (A13), U3.27 (A14), U12.8 (GND), U13.8 (GND), U100.1 (A14), U100.2 (A12), U100.14 (GND), U100.21 (A10), U100.23 (A11), U100.26 (A13); also elsewhere on the board
VCC: C1.1, C10.1, C15.1, C16.2, C17.1, C18.2, J1.30, R1.1, R2.1, R3.1, R44.1, U1.13 (VCC), U3.28 (VCC), U12.16 (VCC), U13.16 (VCC), U100.28 (Vcc); also elsewhere on the board
VDC_R: U13.12 (O3); also elsewhere on the board
VDC_W: U13.13 (O2); also elsewhere on the board

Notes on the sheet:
Revised June 2020: Revised RAM refresh circuit
Revised June 2020: 62256 SRAM
Revised June 2020 - tied /BIOS_OE and /BIOS_CE together for 27C256
Revised October 2021: ~{WAIT} is 2.7k pullup on ChildOfCv schematics
NOTE: I think this GND is actually RF SHIELD GROUND

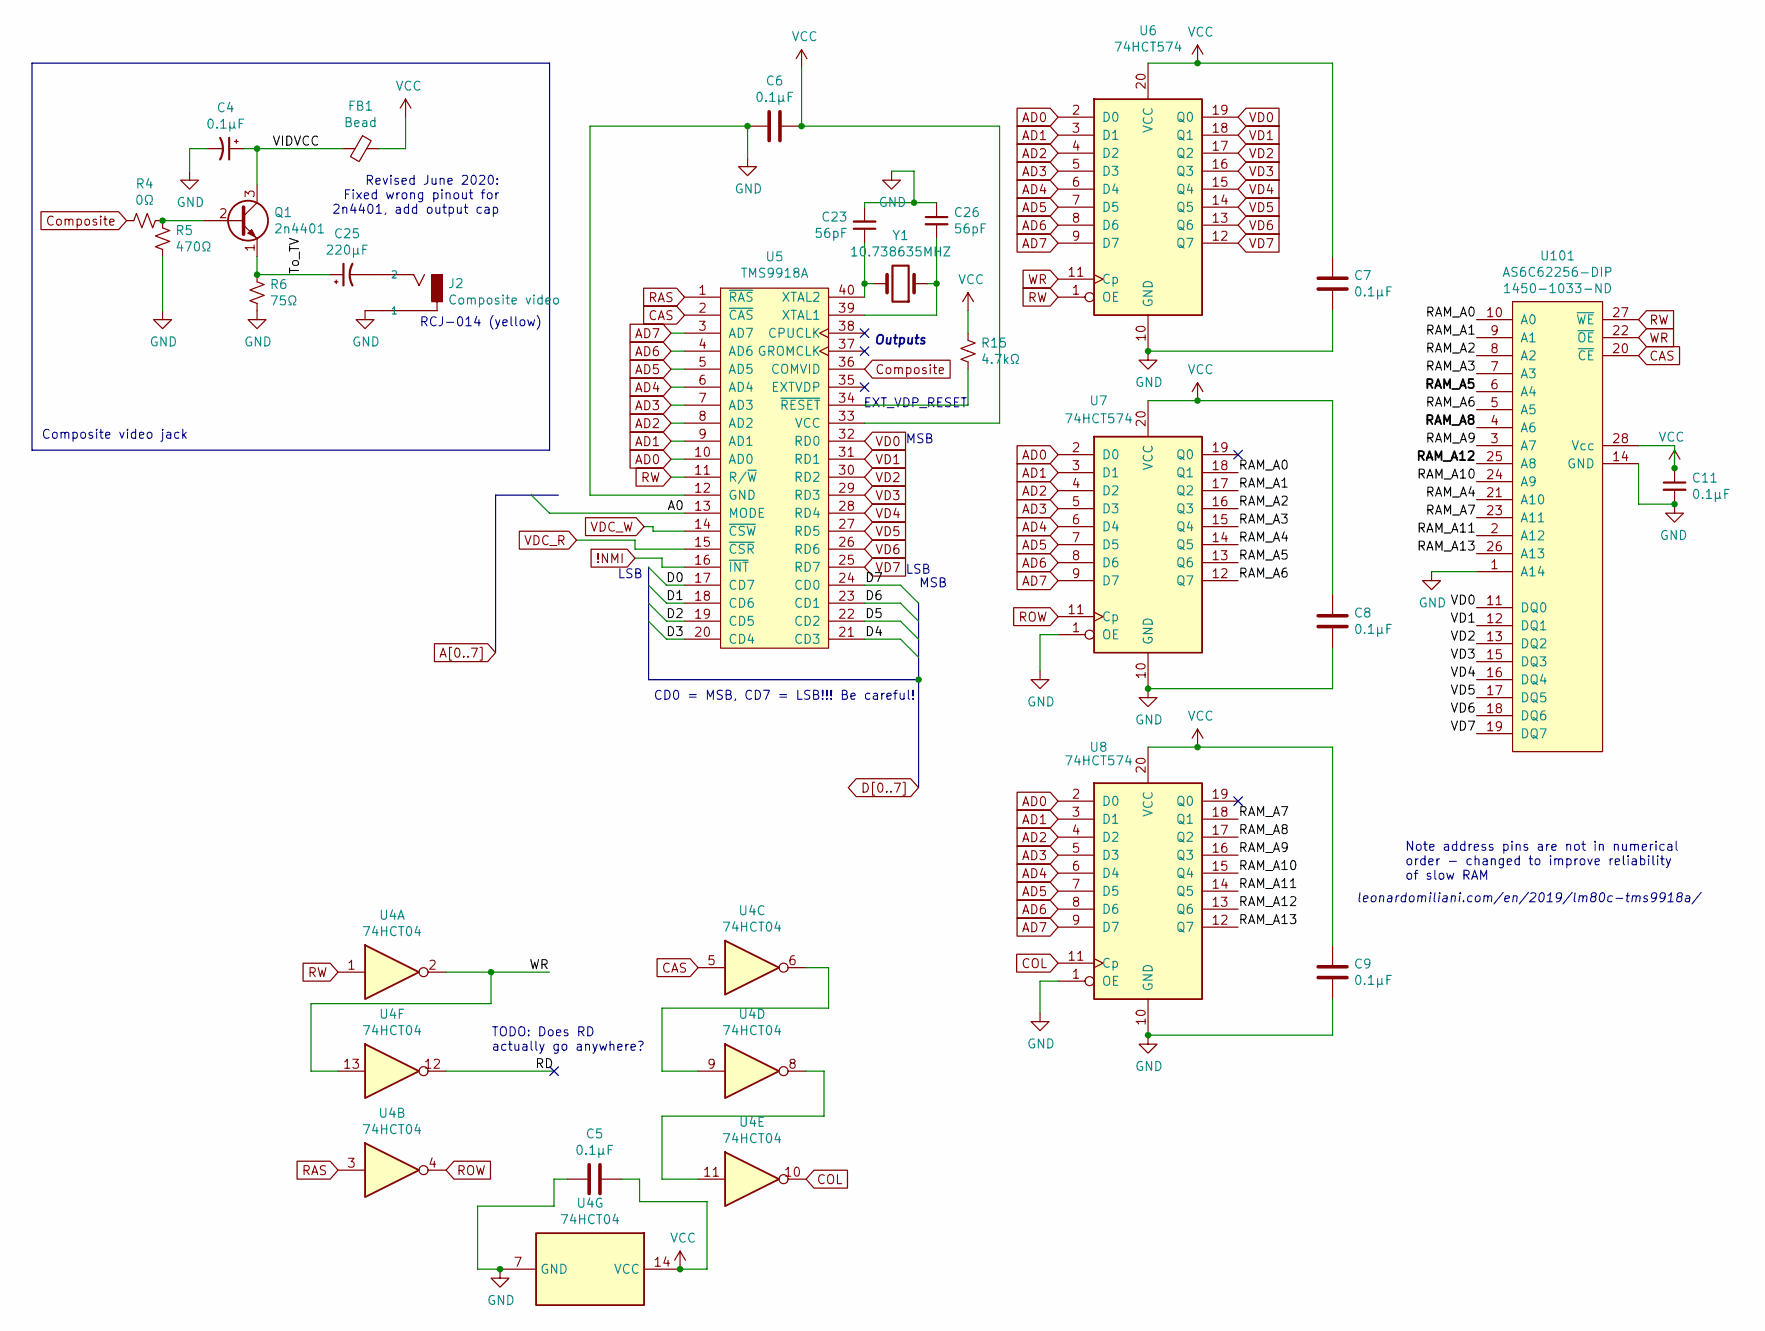
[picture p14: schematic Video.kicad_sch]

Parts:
C4, C5, C6, C7, C8, C9, C11: 0.1µF; C_0805_HandSoldering; DigiKey 1276-1099-1-ND
C23, C26: 56pF; C_0805_HandSoldering; DigiKey 732-7817-1-ND
C25: 220µF; CP_Radial_D6.3mm_P2.50mm; DigiKey 493-15121-ND
FB1: Bead; Choke_SMD_1206_Handsoldering; DigiKey 283-MFBW1V3216-310-RCT-ND
J2: Composite video; CUI_RCJ-017; DigiKey CP-1403-ND‎
Q1: 2n4401; TO-92_Inline_Wide; DigiKey 2N4401TFCT-ND
R4: 0Ω; R_0805_HandSoldering; DigiKey RMCF0805ZT0R00CT-ND
R5: 470Ω; R_0805_HandSoldering; DigiKey RMCF0805JT470RCT-ND
R6: 75Ω; R_0805_HandSoldering; DigiKey RMCF0805JT75R0CT-ND
R15: 4.7kΩ; R_0805_HandSoldering; DigiKey RMCF0805JT4K70CT-ND
U4: 74HCT04; SOIC-14_3.9x8.7mm_Pitch1.27mm; DigiKey 296-31832-1-ND
U5: TMS9918A; DIP-40_W15.24mm_Socket_LongPads; DigiKey ED3048-5-ND
U6, U7, U8: 74HCT574; SOIC-20W_7.5x12.8mm_P1.27mm_LongLegs; DigiKey 1727-2856-1-ND
U101: AS6C62256-DIP; DIP-28_W15.24mm_Socket_LongPads; DigiKey 1450-1033-ND
Y1: 10.738635MHZ; Crystal_HC49-U_Vertical; DigiKey CTX1443-ND

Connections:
!NMI: U5.16 (~INT); also elsewhere on the board
/Video/RAM_A0: U7.18 (Q1), U101.10 (A0)
/Video/RAM_A1: U7.17 (Q2), U101.9 (A1)
/Video/RAM_A2: U7.16 (Q3), U101.8 (A2)
/Video/RAM_A3: U7.15 (Q4), U101.7 (A3)
/Video/RAM_A4: U7.14 (Q5), U101.21 (A10)
/Video/RAM_A5: U7.13 (Q6), U101.6 (A4)
/Video/RAM_A6: U7.12 (Q7), U101.5 (A5)
/Video/RAM_A7: U8.18 (Q1), U101.23 (A11)
/Video/RAM_A8: U8.17 (Q2), U101.4 (A6)
/Video/RAM_A9: U8.16 (Q3), U101.3 (A7)
/Video/RAM_A10: U8.15 (Q4), U101.24 (A9)
/Video/RAM_A11: U8.14 (Q5), U101.2 (A12)
/Video/RAM_A12: U8.13 (Q6), U101.25 (A8)
/Video/RAM_A13: U8.12 (Q7), U101.26 (A13)
/Video/RD: U4.12
/Video/To_TV: C25.1, Q1.1 (E), R6.1
/Video/VIDVCC: C4.1, FB1.2, Q1.3 (C)
A0: U5.13 (MODE); also elsewhere on the board
AD0: U5.10 (AD0), U6.2 (D0), U7.2 (D0), U8.2 (D0)
AD1: U5.9 (AD1), U6.3 (D1), U7.3 (D1), U8.3 (D1)
AD2: U5.8 (AD2), U6.4 (D2), U7.4 (D2), U8.4 (D2)
AD3: U5.7 (AD3), U6.5 (D3), U7.5 (D3), U8.5 (D3)
AD4: U5.6 (AD4), U6.6 (D4), U7.6 (D4), U8.6 (D4)
AD5: U5.5 (AD5), U6.7 (D5), U7.7 (D5), U8.7 (D5)
AD6: U5.4 (AD6), U6.8 (D6), U7.8 (D6), U8.8 (D6)
AD7: U5.3 (AD7), U6.9 (D7), U7.9 (D7), U8.9 (D7)
CAS: U4.5, U5.2 (~CAS), U101.20 (~CE)
COL: U4.10, U8.11 (Cp)
Composite: R4.2, U5.36 (COMVID)
D0: U5.17 (CD7); also elsewhere on the board
D1: U5.18 (CD6); also elsewhere on the board
D2: U5.19 (CD5); also elsewhere on the board
D3: U5.20 (CD4); also elsewhere on the board
D4: U5.21 (CD3); also elsewhere on the board
D5: U5.22 (CD2); also elsewhere on the board
D6: U5.23 (CD1); also elsewhere on the board
D7: U5.24 (CD0); also elsewhere on the board
GND: C4.2, C5.2, C6.2, C7.2, C8.2, C9.2, C11.2, C23.2, C26.1, J2.1A (1), J2.1B (1), J2.1C (1), R5.2, R6.2, U4.7 (GND), U5.12 (GND), U6.10 (GND), U7.1 (OE), U7.10 (GND), U8.1 (OE), U8.10 (GND), U101.1 (A14), U101.14 (GND); also elsewhere on the board
unnamed: C23.1, U5.40 (XTAL2), Y1.2
unnamed: C25.2, J2.2
unnamed: C26.2, U5.39 (XTAL1), Y1.1
unnamed: Q1.2 (B), R4.1, R5.1
unnamed: R15.2, U5.34 (~RESET)
unnamed: U4.6, U4.9
unnamed: U4.8, U4.11
RAS: U4.3, U5.1 (~RAS)
ROW: U4.4, U7.11 (Cp)
RW: U4.1, U5.11 (R/~W), U6.1 (OE), U101.27 (~WE)
VCC: C5.1, C6.1, C7.1, C8.1, C9.1, C11.1, FB1.1, R15.1, U4.14 (VCC), U5.33 (VCC), U6.20 (VCC), U7.20 (VCC), U8.20 (VCC), U101.28 (Vcc); also elsewhere on the board
VD0: U5.32 (RD0), U6.19 (Q0), U101.11 (DQ0)
VD1: U5.31 (RD1), U6.18 (Q1), U101.12 (DQ1)
VD2: U5.30 (RD2), U6.17 (Q2), U101.13 (DQ2)
VD3: U5.29 (RD3), U6.16 (Q3), U101.15 (DQ3)
VD4: U5.28 (RD4), U6.15 (Q4), U101.16 (DQ4)
VD5: U5.27 (RD5), U6.14 (Q5), U101.17 (DQ5)
VD6: U5.26 (RD6), U6.13 (Q6), U101.18 (DQ6)
VD7: U5.25 (RD7), U6.12 (Q7), U101.19 (DQ7)
VDC_R: U5.15 (~CSR); also elsewhere on the board
VDC_W: U5.14 (~CSW); also elsewhere on the board
WR: U4.2, U4.13, U6.11 (Cp), U101.22 (~OE)

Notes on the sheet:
leonardomiliani.com/en/2019/lm80c-tms9918a/
TODO: Does RD actually go anywhere?
EXT_VDP_RESET
LSB
CD0 = MSB, CD7 = LSB!!! Be careful!
Composite video jack
Note address pins are not in numerical order - changed to improve reliability of slow RAM
RCJ-014 (yellow)
Revised June 2020: Fixed wrong pinout for 2n4401, add output cap
MSB
Outputs

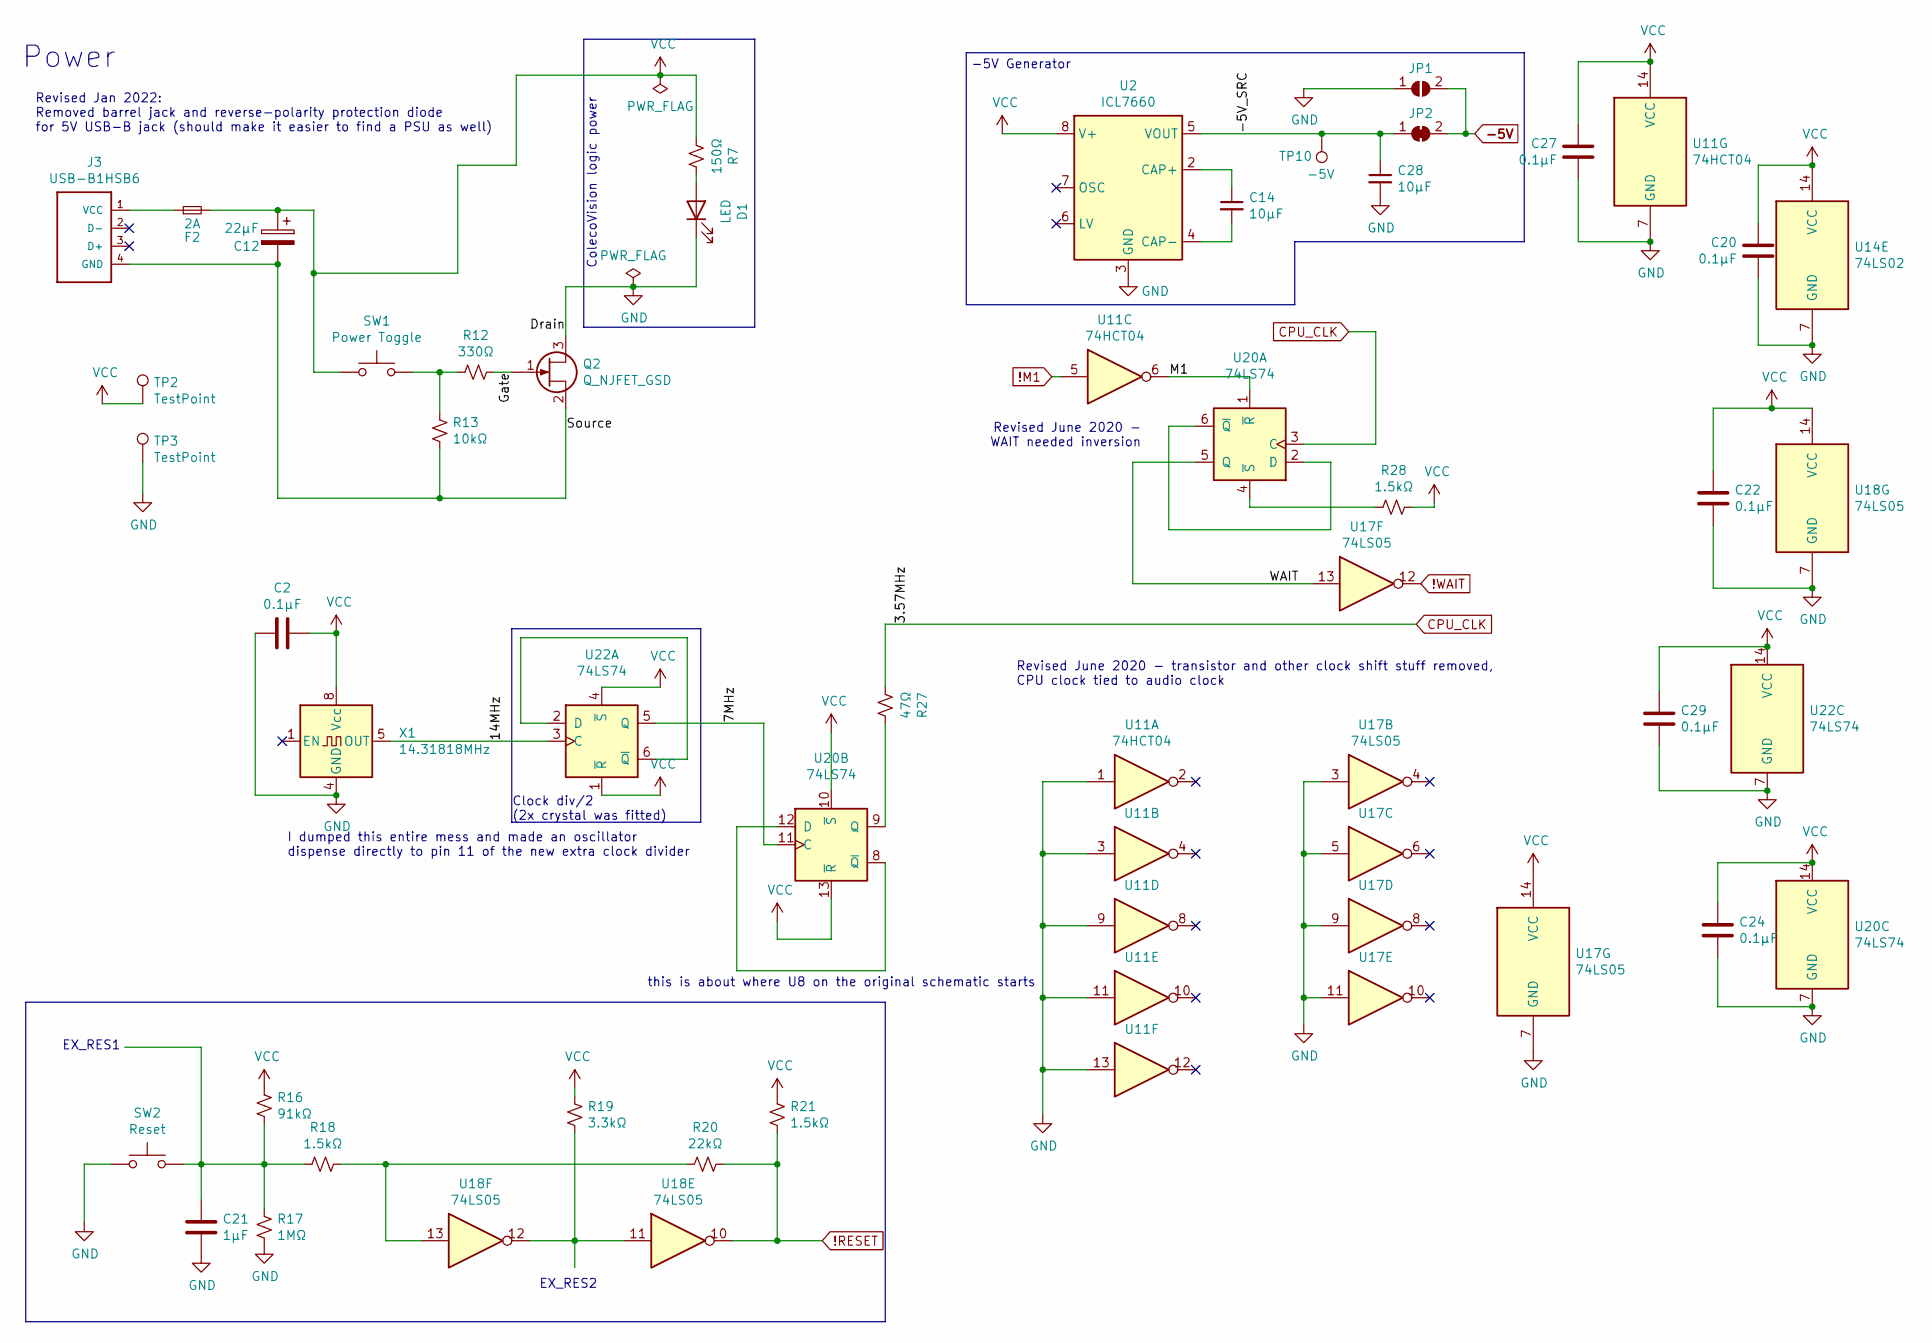
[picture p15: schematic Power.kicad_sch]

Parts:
C2, C20, C22, C24, C27, C29: 0.1µF; C_0805_HandSoldering; DigiKey 1276-1099-1-ND
C12: 22µF; CP_Radial_D5.0mm_P2.50mm; DigiKey 493-1037-ND
C14, C28: 10µF; C_0805_2012Metric_Pad1.15x1.40mm_HandSolder; DigiKey 1276-1298-1-ND
C21: 1µF; C_0805_HandSoldering; DigiKey 1276-2926-1-ND
D1: LED; LED_D3.0mm; DigiKey 1497-1022-ND
F2: 2A; 0251002.MRT1L; DigiKey F3171CT-ND
J3: USB-B1HSB6; OST_USB-B1HSB6; DigiKey ED2982-ND
JP1: SolderJumper_2_Open; SolderJumper-2_P1.3mm_Open_Pad1.0x1.5mm
JP2: SolderJumper_2_Bridged; SolderJumper-2_P1.3mm_Bridged_Pad1.0x1.5mm
Q2: Q_NJFET_GSD; SOT-23_Handsoldering; DigiKey DMN2046U-7DICT-ND
R7: 150Ω; R_0805_HandSoldering; DigiKey RMCF0805JT150RCT-ND
R12: 330Ω; R_0805_HandSoldering; DigiKey RMCF0805JT330RCT-ND
R13: 10kΩ; R_0805_HandSoldering; DigiKey RMCF0805JT10K0CT-ND
R16: 91kΩ; R_0805_HandSoldering; DigiKey RMCF0805JT91K0CT-ND
R17: 1MΩ; R_0805_HandSoldering; DigiKey RMCF0805JT1M00CT-ND
R18, R21, R28: 1.5kΩ; R_0805_HandSoldering; DigiKey RMCF0805FT1K00CT-ND
R19: 3.3kΩ; R_0805_HandSoldering; DigiKey RMCF0805JT3K30CT-ND
R20: 22kΩ; R_0805_HandSoldering; DigiKey RMCF0805JT22K0CT-ND
R27: 47Ω; R_0805_HandSoldering; DigiKey RMCF0805JT47R0CT-ND
SW1: Power Toggle; PVA1_Switch; DigiKey 401-1132-ND
SW2: Reset; SW_PUSH_6mm; DigiKey 679-2428-ND
TP2, TP3: TestPoint; Measurement_Point_Round-TH_Small
TP10: -5V; TestPoint_Loop_D1.80mm_Drill1.0mm_Beaded
U2: ICL7660; SOIC-8_3.9x4.9mm_P1.27mm; DigiKey ICL7660CSA+TCT-ND
U11: 74HCT04; SOIC-14_3.9x8.7mm_Pitch1.27mm; DigiKey 296-31832-1-ND
U14: 74LS02; SOIC-14_3.9x8.7mm_Pitch1.27mm; DigiKey 296-14874-1-ND
U17: 74LS05; DigiKey 296-1630-1-ND
U18: 74LS05; SOIC-14_3.9x8.7mm_Pitch1.27mm; DigiKey 296-1630-1-ND
U20, U22: 74LS74; SOIC-14_3.9x8.7mm_Pitch1.27mm; DigiKey 296-14899-1-ND
X1: 14.31818MHz; Oscillator_DIP-8_LargePads; DigiKey 535-9170-5-ND

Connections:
!M1: U11.5; also elsewhere on the board
!RESET: R20.1, R21.2, U18.10; also elsewhere on the board
!WAIT: U17.12; also elsewhere on the board
-5V: JP1.2 (B), JP2.2 (B); also elsewhere on the board
/Power/7MHz: U20.11 (C), U22.5 (Q)
/Power/14MHz: U22.3 (C), X1.5 (OUT)
/Power/-5V_SRC: C28.1, JP2.1 (A), TP10.1, U2.5 (VOUT)
/Power/Gate: Q2.1 (G), R12.1
/Power/M1: U11.6, U20.1 (~R)
/Power/Source: C12.2, J3.4 (GND), Q2.2 (S), R13.2
/Power/WAIT: U17.13, U20.5 (Q)
CPU_CLK: R27.2, U20.3 (C); also elsewhere on the board
GND: C2.2, C20.1, C21.2, C22.2, C24.2, C27.1, C28.2, C29.2, D1.1 (K), JP1.1 (A), Q2.3 (D), R17.2, SW2.1, TP3.1, U2.3 (GND), U11.1, U11.3, U11.7 (GND), U11.9, U11.11, U11.13, U14.7 (GND), U17.3, U17.5, U17.7 (GND), U17.9, U17.11, U18.7 (GND), U20.7 (GND), U22.7 (GND), X1.4 (GND); also elsewhere on the board
unnamed: C14.1, U2.2 (CAP+)
unnamed: C14.2, U2.4 (CAP-)
unnamed: C21.1, R16.2, R17.1, R18.2, SW2.2
unnamed: D1.2 (A), R7.1
unnamed: F2.1, J3.1 (VCC)
unnamed: R12.2, R13.1, SW1.2
unnamed: R18.1, R20.2, U18.13
unnamed: R19.2, U18.11, U18.12
unnamed: R27.1, U20.9 (Q)
unnamed: R28.2, U20.4 (~S)
unnamed: U20.2 (D), U20.6 (~Q)
unnamed: U20.8 (~Q), U20.12 (D)
unnamed: U22.2 (D), U22.6 (~Q)
VCC: C2.1, C12.1, C20.2, C22.1, C24.1, C27.2, C29.1, F2.2, R7.2, R16.1, R19.1, R21.1, R28.1, SW1.1, TP2.1, U2.8 (V+), U11.14 (VCC), U14.14 (VCC), U17.14 (VCC), U18.14 (VCC), U20.10 (~S), U20.13 (~R), U20.14 (VCC), U22.1 (~R), U22.4 (~S), U22.14 (VCC), X1.8 (Vcc); also elsewhere on the board

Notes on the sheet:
Power
Revised June 2020 - WAIT needed inversion
ColecoVision logic power
I dumped this entire mess and made an oscillator dispense directly to pin 11 of the new extra clock divider
EX_RES2
Revised June 2020 - transistor and other clock shift stuff removed, CPU clock tied to audio clock
Clock div/2 (2x crystal was fitted)
Revised Jan 2022: Removed barrel jack and reverse-polarity protection diode for 5V USB-B jack (should make it easier to find a PSU as well)
EX_RES1
this is about where U8 on the original schematic starts
-5V Generator

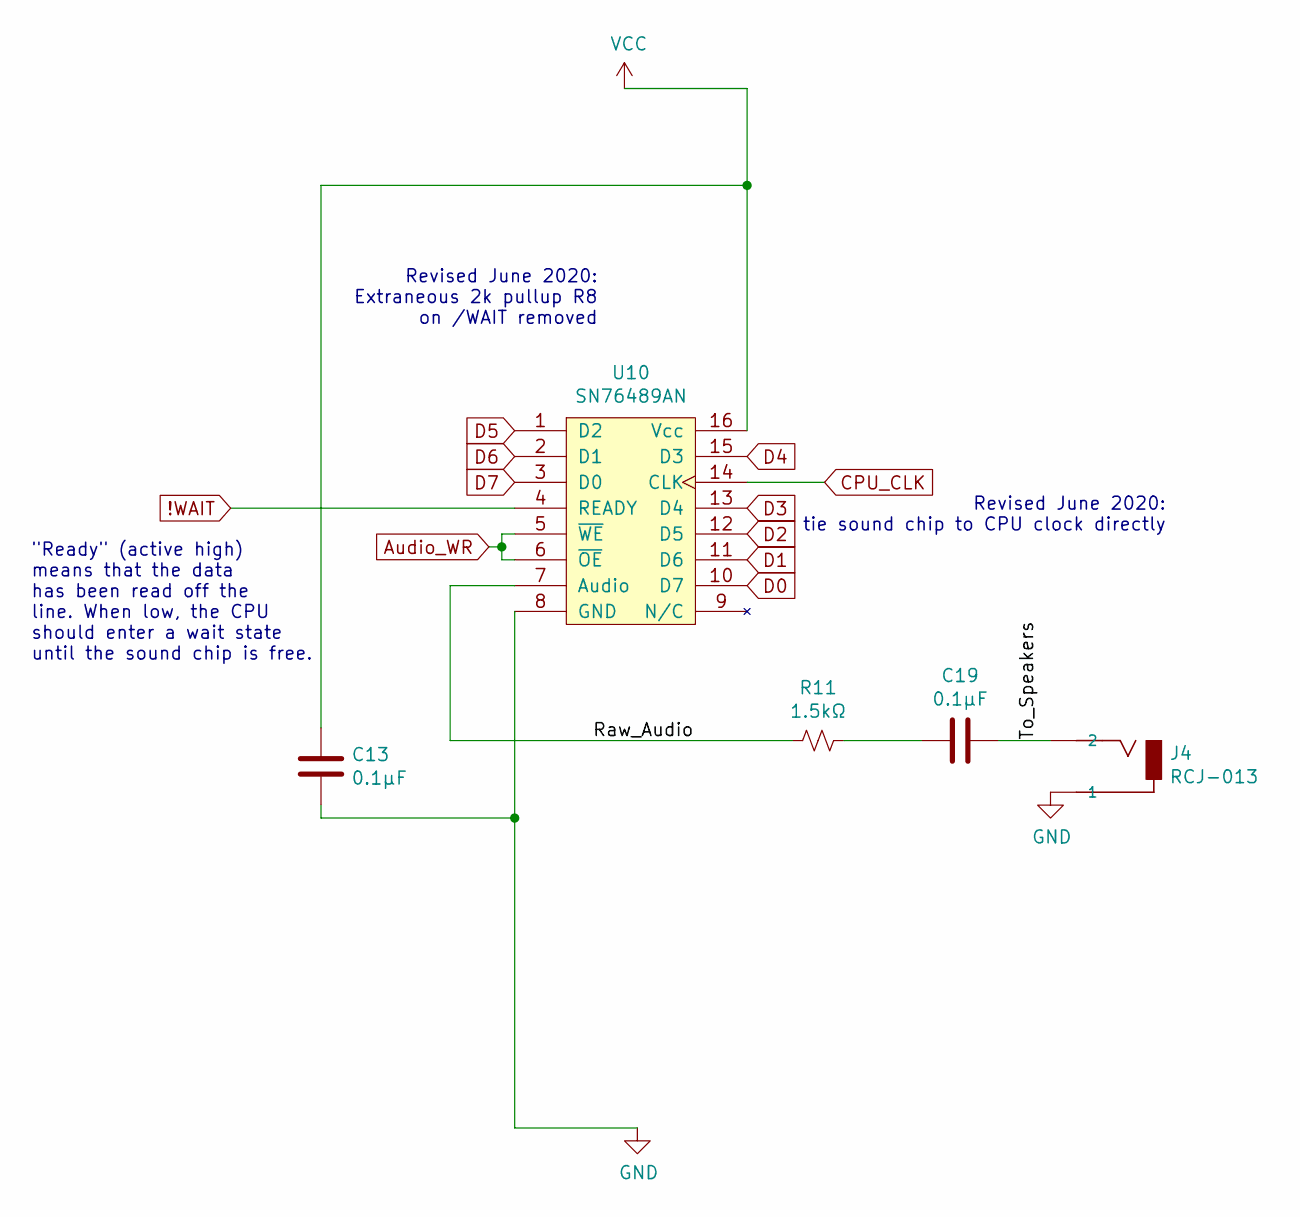
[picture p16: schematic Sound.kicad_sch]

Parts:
C13, C19: 0.1µF; C_0805_HandSoldering; DigiKey 1276-1099-1-ND
J4: RCJ-013; CUI_RCJ-017; DigiKey CP-1402-ND‎
R11: 1.5kΩ; R_0805_HandSoldering; DigiKey RMCF0805FT1K00CT-ND
U10: SN76489AN; DIP-16_W7.62mm_Socket_LongPads; DigiKey AE9992-ND

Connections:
!WAIT: U10.4 (READY); also elsewhere on the board
/Sound/Raw_Audio: R11.2, U10.7 (Audio)
/Sound/To_Speakers: C19.1, J4.2
Audio_WR: U10.5 (~WE), U10.6 (~OE); also elsewhere on the board
CPU_CLK: U10.14 (CLK); also elsewhere on the board
D0: U10.10 (D7); also elsewhere on the board
D1: U10.11 (D6); also elsewhere on the board
D2: U10.12 (D5); also elsewhere on the board
D3: U10.13 (D4); also elsewhere on the board
D4: U10.15 (D3); also elsewhere on the board
D5: U10.1 (D2); also elsewhere on the board
D6: U10.2 (D1); also elsewhere on the board
D7: U10.3 (D0); also elsewhere on the board
GND: C13.2, J4.1A (1), J4.1B (1), J4.1C (1), U10.8 (GND); also elsewhere on the board
unnamed: C19.2, R11.1
VCC: C13.1, U10.16 (Vcc); also elsewhere on the board

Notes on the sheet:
"Ready" (active high) means that the data has been read off the line. When low, the CPU should enter a wait state until the sound chip is free.
Revised June 2020: Extraneous 2k pullup R8 on /WAIT removed
Revised June 2020: tie sound chip to CPU clock directly

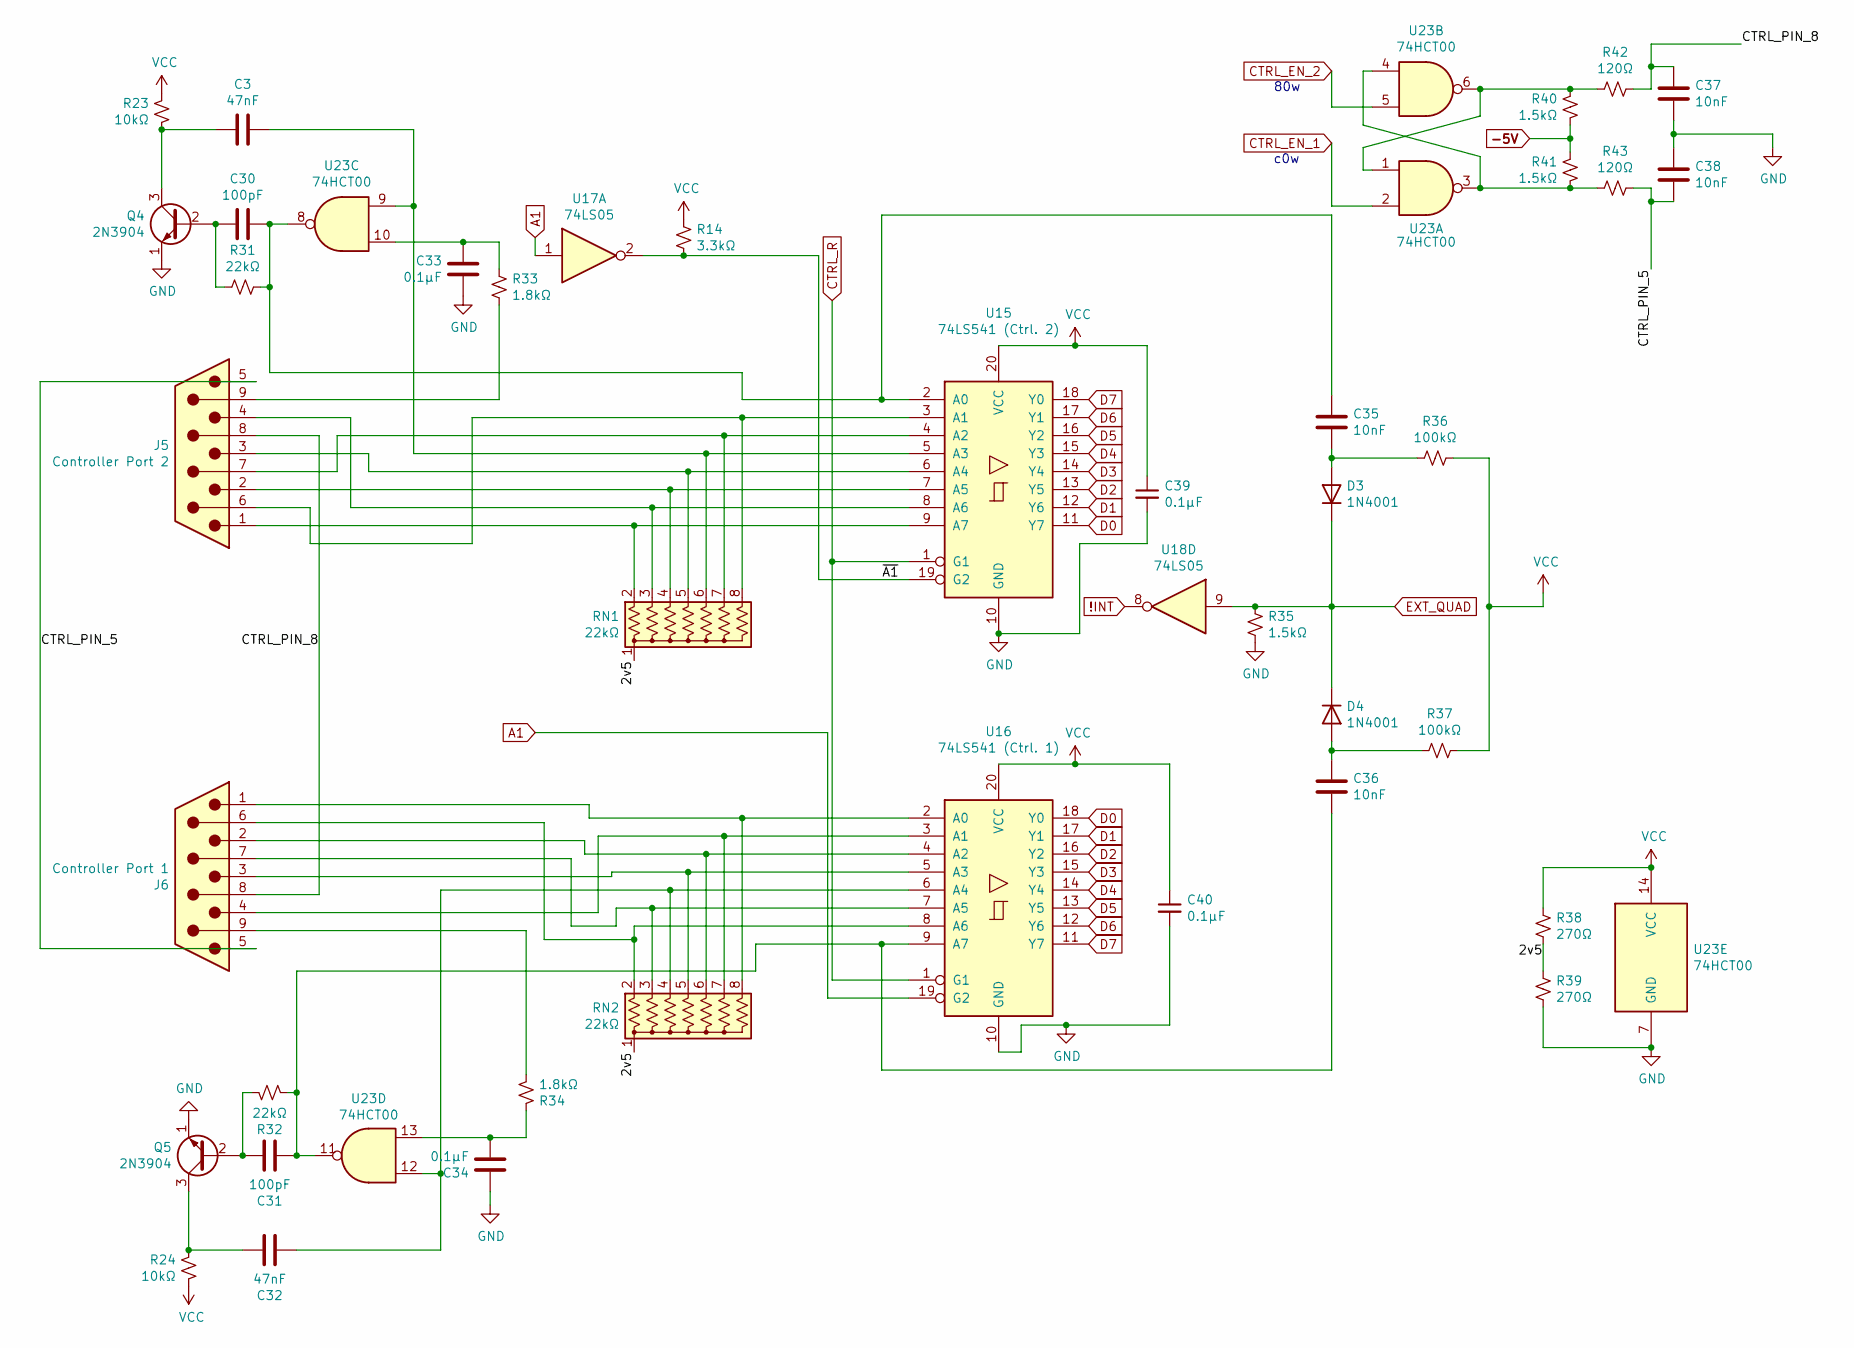
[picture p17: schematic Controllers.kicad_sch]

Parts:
C3, C32: 47nF; C_0805_HandSoldering; DigiKey 732-8059-1-ND
C30, C31: 100pF; C_0805_HandSoldering; DigiKey 732-12161-1-ND
C33, C34: 0.1µF; C_0805_HandSoldering; DigiKey 1276-1099-1-ND
C35, C36, C37, C38: 10nF; C_0805_HandSoldering; DigiKey 399-C0805X103K1RAC3316CT-ND
C39, C40: 0.1µF; C_0805_2012Metric_Pad1.15x1.40mm_HandSolder; DigiKey 1276-1099-1-ND
D3, D4: 1N4001; D_DO-41_SOD81_P2.54mm_Vertical_AnodeUp; DigiKey 641-1310-1-ND
J5: Controller Port 2; A-DS 09 A-KG-T2S; DigiKey AE10968-ND
J6: Controller Port 1; A-DS 09 A-KG-T2S; DigiKey AE10968-ND
Q4, Q5: 2N3904; TO-92_Inline_Wide; DigiKey 2N3904TAFSCT-ND
R14: 3.3kΩ; R_0805_HandSoldering; DigiKey RMCF0805JT3K30CT-ND
R23, R24: 10kΩ; R_0805_HandSoldering; DigiKey RMCF0805JT10K0CT-ND
R31, R32: 22kΩ; R_0805_HandSoldering; DigiKey RMCF0805JT22K0CT-ND
R33, R34: 1.8kΩ; R_0805_HandSoldering; DigiKey RMCF0805JT1K80CT-ND
R35, R40, R41: 1.5kΩ; R_0805_HandSoldering; DigiKey RMCF0805JT1K50CT-ND
R36, R37: 100kΩ; R_0805_HandSoldering; DigiKey RMCF0805JT100KCT-ND
R38, R39: 270Ω; R_0805_HandSoldering; DigiKey RMCF0805JT270RCT-ND
R42, R43: 120Ω; R_0805_HandSoldering; DigiKey RMCF0805JT120RCT-ND
RN1, RN2: 22kΩ; R_Array_SIP8; DigiKey 4608X-1-223LF-ND
U15: 74LS541 (Ctrl. 2); SOIC-20W_7.5x12.8mm_P1.27mm; DigiKey 296-14870-1-ND
U16: 74LS541 (Ctrl. 1); SOIC-20W_7.5x12.8mm_P1.27mm; DigiKey 296-14870-1-ND
U17, U18: 74LS05; SOIC-14_3.9x8.7mm_Pitch1.27mm; DigiKey 296-1630-1-ND
U23: 74HCT00; SOIC-14_3.9x8.7mm_Pitch1.27mm; DigiKey 296-14542-1-ND

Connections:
!INT: U18.8; also elsewhere on the board
-5V: R40.1, R41.2; also elsewhere on the board
/Controllers/2v5: R38.2, R39.1, RN1.1 (common), RN2.1 (common)
/Controllers/CTRL_PIN_5: C38.2, J5.5, J6.5, R43.1
/Controllers/CTRL_PIN_8: C37.1, J5.8, J6.8, R42.1
/Controllers/~A1: R14.2, U15.19 (G2), U17.2
A1: U16.19 (G2), U17.1; also elsewhere on the board
CTRL_EN_1: U23.2; also elsewhere on the board
CTRL_EN_2: U23.5; also elsewhere on the board
CTRL_R: U15.1 (G1), U16.1 (G1); also elsewhere on the board
D0: U15.11 (Y7), U16.18 (Y0); also elsewhere on the board
D1: U15.12 (Y6), U16.17 (Y1); also elsewhere on the board
D2: U15.13 (Y5), U16.16 (Y2); also elsewhere on the board
D3: U15.14 (Y4), U16.15 (Y3); also elsewhere on the board
D4: U15.15 (Y3), U16.14 (Y4); also elsewhere on the board
D5: U15.16 (Y2), U16.13 (Y5); also elsewhere on the board
D6: U15.17 (Y1), U16.12 (Y6); also elsewhere on the board
D7: U15.18 (Y0), U16.11 (Y7); also elsewhere on the board
EXT_QUAD: D3.1 (K), D4.1 (K), R35.2, U18.9; also elsewhere on the board
GND: C33.1, C34.2, C37.2, C38.1, C39.2, C40.2, Q4.1 (E), Q5.1 (E), R35.1, R39.2, U15.10 (GND), U16.10 (GND), U23.7 (GND); also elsewhere on the board
unnamed: C3.1, RN1.6 (R5), U15.5 (A3), U23.9
unnamed: C3.2, Q4.3 (C), R23.1
unnamed: C30.1, C35.1, R31.1, U15.2 (A0), U23.8
unnamed: C30.2, Q4.2 (B), R31.2
unnamed: C31.1, C36.2, R32.1, U16.9 (A7), U23.11
unnamed: C31.2, Q5.2 (B), R32.2
unnamed: C32.1, RN2.4 (R3), U16.6 (A4), U23.12
unnamed: C32.2, Q5.3 (C), R24.2
unnamed: C33.2, R33.2, U23.10
unnamed: C34.1, R34.2, U23.13
unnamed: C35.2, D3.2 (A), R36.2
unnamed: C36.1, D4.2 (A), R37.2
unnamed: J5.1, RN1.2 (R1), U15.9 (A7)
unnamed: J5.2, RN1.4 (R3), U15.7 (A5)
unnamed: J5.3, RN1.5 (R4), U15.6 (A4)
unnamed: J5.4, RN1.3 (R2), U15.8 (A6)
unnamed: J5.6, RN1.8 (R7), U15.3 (A1)
unnamed: J5.7, RN1.7 (R6), U15.4 (A2)
unnamed: J5.9, R33.1
unnamed: J6.1, RN2.8 (R7), U16.2 (A0)
unnamed: J6.2, RN2.6 (R5), U16.4 (A2)
unnamed: J6.3, RN2.5 (R4), U16.5 (A3)
unnamed: J6.4, RN2.7 (R6), U16.3 (A1)
unnamed: J6.6, RN2.2 (R1), U16.8 (A6)
unnamed: J6.7, RN2.3 (R2), U16.7 (A5)
unnamed: J6.9, R34.1
unnamed: R40.2, R42.2, U23.1, U23.6
unnamed: R41.1, R43.2, U23.3, U23.4
VCC: C39.1, C40.1, R14.1, R23.2, R24.1, R36.1, R37.1, R38.1, U15.20 (VCC), U16.20 (VCC), U23.14 (VCC); also elsewhere on the board

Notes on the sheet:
c0w
80w

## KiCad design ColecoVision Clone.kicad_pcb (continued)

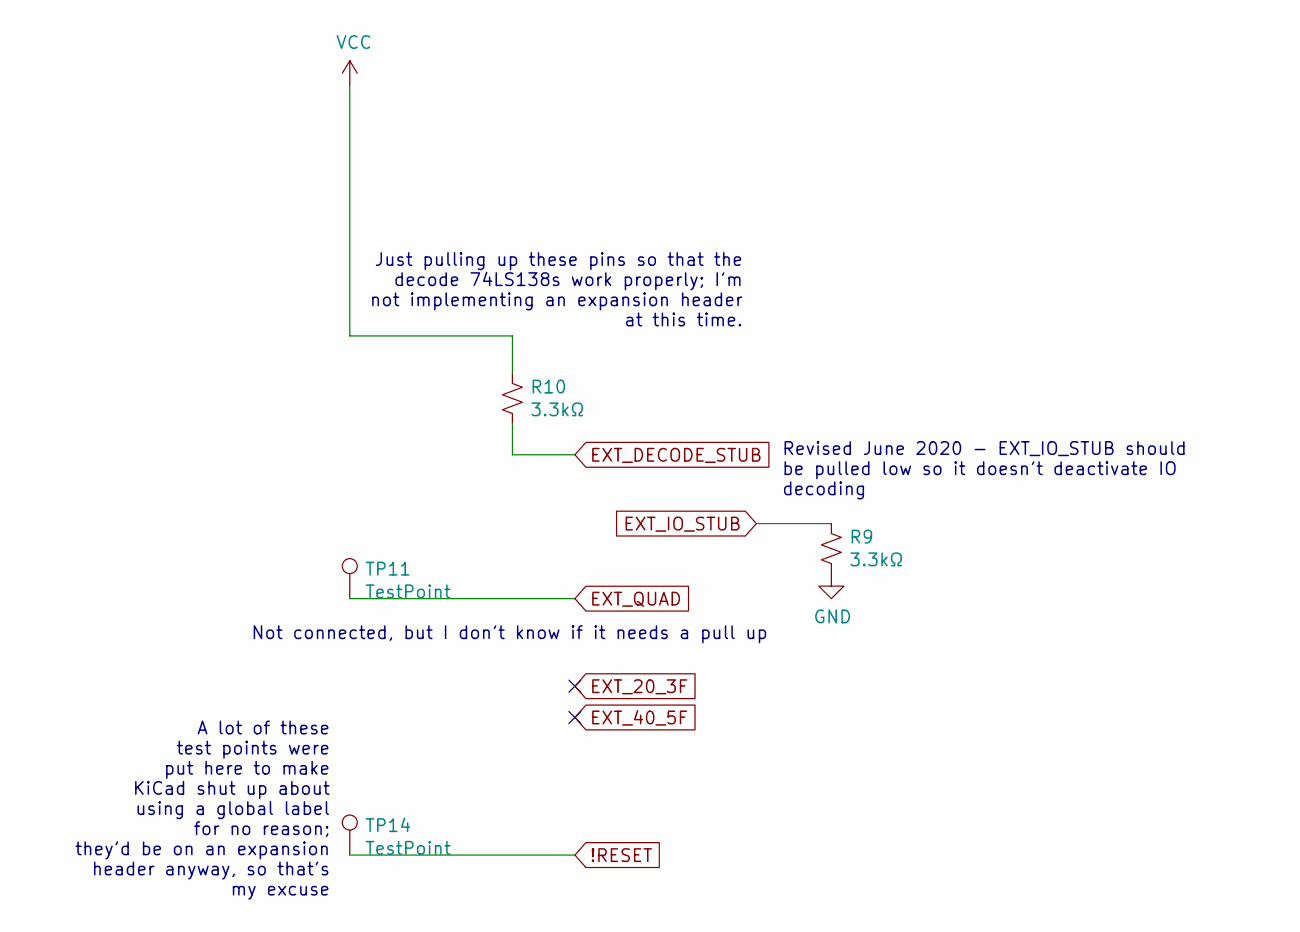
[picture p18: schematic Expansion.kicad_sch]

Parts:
R9, R10: 3.3kΩ; R_0805_HandSoldering; DigiKey RMCF0805JT3K30CT-ND
TP11: TestPoint; Measurement_Point_Round-TH_Small
TP14: TestPoint; Measurement_Point_Round-SMD-Pad_Small

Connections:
!RESET: TP14.1; also elsewhere on the board
EXT_DECODE_STUB: R10.2; also elsewhere on the board
EXT_IO_STUB: R9.2; also elsewhere on the board
EXT_QUAD: TP11.1; also elsewhere on the board
GND: R9.1; also elsewhere on the board
VCC: R10.1; also elsewhere on the board

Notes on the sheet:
Just pulling up these pins so that the decode 74LS138s work properly; I'm not implementing an expansion header at this time.
A lot of these test points were put here to make KiCad shut up about using a global label for no reason; they'd be on an expansion header anyway, so that's my excuse
Revised June 2020 - EXT_IO_STUB should be pulled low so it doesn't deactivate IO decoding
Not connected, but I don't know if it needs a pull up

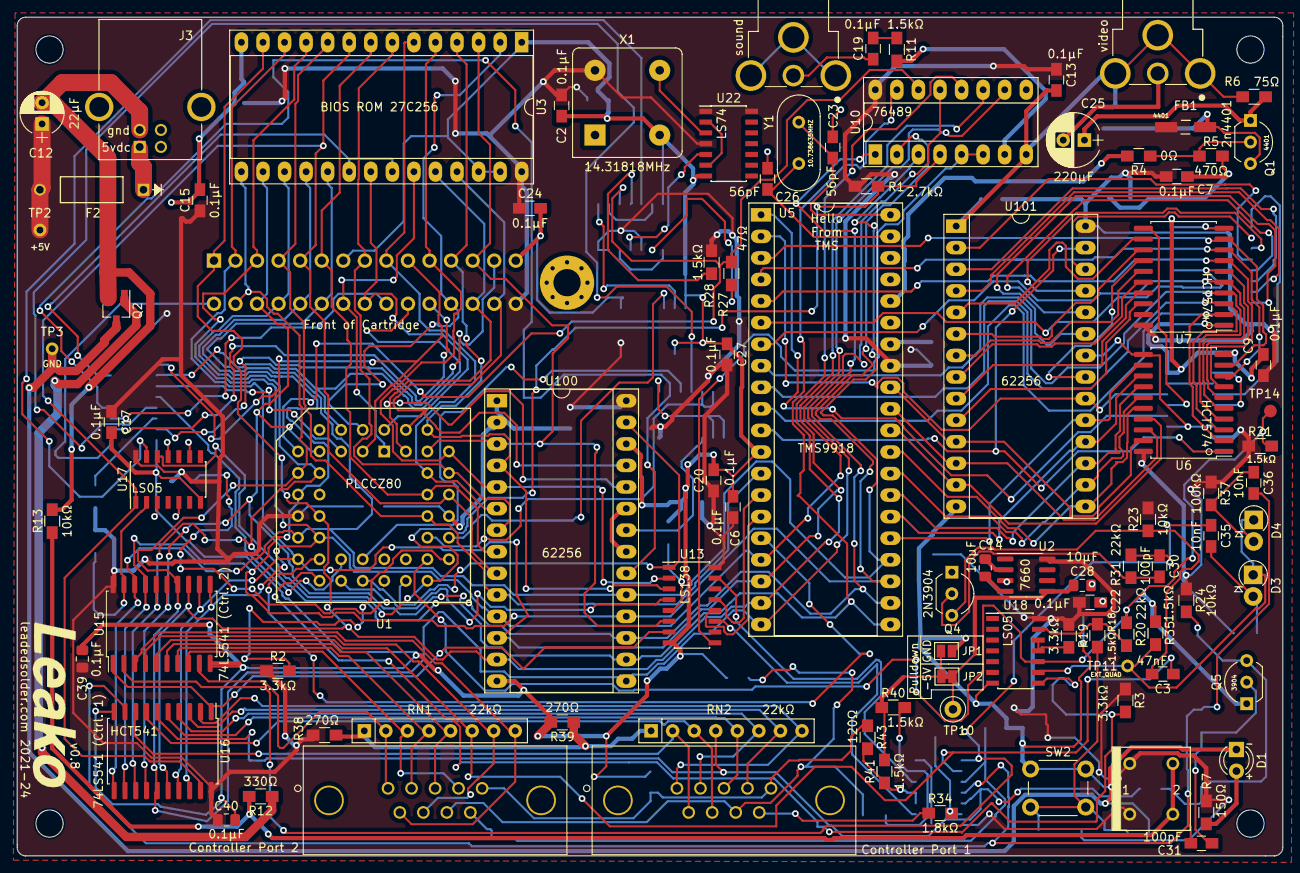
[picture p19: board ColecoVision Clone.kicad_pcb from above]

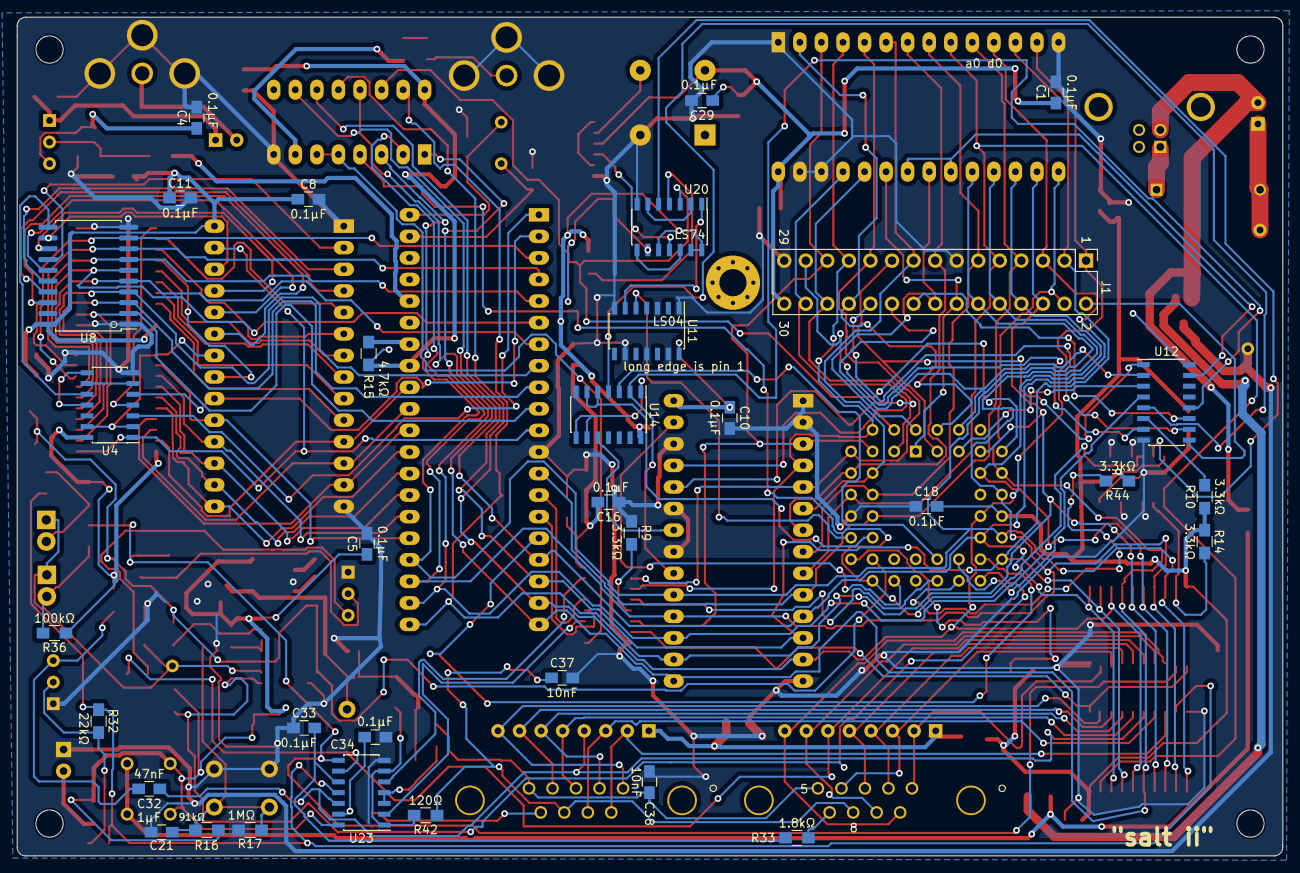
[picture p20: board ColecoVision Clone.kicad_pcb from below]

Board: 2 copper layers, 149.1 x 98.8 mm, 128 parts (34 on the bottom side), 159 nets.

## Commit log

2020-02-03 Early PCB - just cart slot and CPU
    [ColecoVision Clone.kicad_pcb, ColecoVision Clone.sch]
2020-02-03 Partially fucked up chip layout
    [ColecoVision Clone.sch]
2020-02-03 Not happy with label posn but it's workign
    [ColecoVision Clone.sch]
2020-02-03 SOIC-40 footprint, needs testing
    [ColecoVision Clone.kicad_pcb, ColecoVision Clone.sch]
2020-02-03 This is fun, and hard
    [ColecoVision Clone.kicad_pcb, ColecoVision Clone.sch, Video.sch]
2020-02-03 Leako logo
    [ColecoVision Clone.kicad_pcb]
2020-02-04 Added a bunch of shit we don't need to distract me from doing RAM decoding
    [ColecoVision Clone.kicad_pcb, ColecoVision Clone.sch, Power.sch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]
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2020-02-04 Kinda wiring up D-pins
    [ColecoVision Clone.kicad_pcb, ColecoVision Clone.sch]
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2020-02-04 Blindly hooking up vram bus
    [ColecoVision Clone.kicad_pcb, ColecoVision Clone.sch, Video.sch]
2020-02-05 Not sure I know enough to set up the VRAM bus yet
    [ColecoVision Clone.kicad_pcb, Video.sch]
2020-02-05 Get rid of RD0 speculation
    [Video.sch]
2020-02-06 COMVID and Crystal from PDF
    [ColecoVision Clone.kicad_pcb, ColecoVision Clone.sch, Power.sch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]
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2020-02-06 Entire VRAM decoder laid out
    [ColecoVision Clone.kicad_pcb, Power.sch, Video.sch]
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2020-02-06 Audio jack no amp
    [ColecoVision Clone.kicad_pcb, ColecoVision Clone.sch, Power.sch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]
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2020-02-06 Add the logo AGAIN
    [ColecoVision Clone.kicad_pcb]
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2020-02-06 RAM, Cart, BIOS address pins
    [ColecoVision Clone.kicad_pcb, ColecoVision Clone.sch]
2020-02-06 Start plumbing out enable pins
    [ColecoVision Clone.sch]
2020-02-06 OE CE for RAM
    [ColecoVision Clone.sch]
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2020-02-06 BIOS CE mystery solved
    [ColecoVision Clone.sch]
2020-02-06 RAM finally write enabled
    [ColecoVision Clone.sch]
2020-02-06 Cleaning up some old labels
    [ColecoVision Clone.kicad_pcb, ColecoVision Clone.sch, Video.sch]
2020-02-06 Why even use buses
    [ColecoVision Clone.sch, Video.sch]
2020-02-07 Clean up power flags
    [ColecoVision Clone.kicad_pcb, ColecoVision Clone.sch, Power.sch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]
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2020-02-08 Pull-up on expansion header
    [ColecoVision Clone.kicad_pcb, ColecoVision Clone.sch, Expansion.sch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]
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2020-02-08 Get rid of amp
    [ColecoVision Clone.kicad_pcb, Sound.sch]
2020-02-08 Better power switch found
    [ColecoVision Clone.kicad_pcb, Power.sch, Sound.sch]
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2020-02-08 Swap tip and ring for composite, finish up power
    [ColecoVision Clone.kicad_pcb, Controllers.sch, Power.sch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]
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2020-02-09 More messing with controllers
    [ColecoVision Clone.kicad_pcb, Controllers.sch]
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2020-02-09 Add test point bodges
    [ColecoVision Clone.kicad_pcb, ColecoVision Clone.sch, Controllers.sch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]
2020-02-09 Reset circuit
    [ColecoVision Clone.kicad_pcb, Power.sch, Video.sch]
2020-02-09 Do not allow CPU to reset VDP
    [Power.sch, Video.sch]
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2020-02-09 CPU clock detached from VDP
    [Video.sch]
2020-02-09 [PCB] CPU clock detached from VDP
    [ColecoVision Clone.kicad_pcb]
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2020-02-10 Soon the clock nightmare will be over
    [ColecoVision Clone.kicad_pcb, Power.sch]
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2020-02-11 All the controller stuff is on the PCB now
    [ColecoVision Clone.kicad_pcb, Controllers.sch, Power.sch]
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2020-02-11 Put power and ground pins on more logic
    [ColecoVision Clone.kicad_pcb, Power.sch]
2020-02-11 Knocking out bugs
    [ColecoVision Clone.kicad_pcb, ColecoVision Clone.sch, Controllers.sch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]
2020-02-11 Bugs patched
    [ColecoVision Clone.kicad_pcb, ColecoVision Clone.sch, Controllers.sch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]
2020-02-11 RAM wired up but i don't like it
    [ColecoVision Clone.kicad_pcb]
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2020-02-12 that's enough for one night
    [ColecoVision Clone.kicad_pcb]
2020-02-12 Slowly stitching up the TMS
    [ColecoVision Clone.kicad_pcb]
2020-02-12 Cart Enable wired up
    [ColecoVision Clone.kicad_pcb]
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2020-02-13 Sound chip plugged into data bus
    [ColecoVision Clone.kicad_pcb]
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2020-02-13 Goodbye to one inverter
    [ColecoVision Clone.kicad_pcb, ColecoVision Clone.sch]
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2020-02-13 I think just decoupling caps now
    [ColecoVision Clone.kicad_pcb]
2020-02-13 the L is in
    [ColecoVision Clone.kicad_pcb]
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2020-02-13 Reset passives
    [ColecoVision Clone.kicad_pcb]
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2020-02-13 Bits and bobs - ready for decouplers
    [ColecoVision Clone.kicad_pcb]
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2020-02-14 it's all in there baby
    [ColecoVision Clone.kicad_pcb]
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2020-02-19 reverse data bus for 76489
    [ColecoVision Clone.kicad_pcb, Sound.sch]
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2020-02-24 Fix clock circuit - v0.2
    [ColecoVision Clone.kicad_pcb, ColecoVision Clone.sch, Power.sch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]
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2020-02-27 Move Q3 out of the way of the cartridge
    [ColecoVision Clone.kicad_pcb]
2020-02-29 Drop a 74ls05 and use a NOR gate instead
    [ColecoVision Clone.kicad_pcb, ColecoVision Clone.sch, Power.sch]
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2020-03-14 new cart slot, hope clearance is good
    [ColecoVision Clone.kicad_pcb, ColecoVision Clone.sch]
2020-03-14 Get rid of cartridge slot silkscreen since it is probably wrong
    [ColecoVision Clone.kicad_pcb]
2020-03-14 Move the confusing decoupling cap away from the crystal holes
    [ColecoVision Clone.kicad_pcb]
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2020-03-25 Cleaning up v0.3 with some of the assembly findings
    [ColecoVision Clone.kicad_pcb]
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2020-03-25 Unit fix again
    [Controllers.sch]
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2020-03-26 Move the circuit into the right spot of the page
    [ColecoVision Clone.kicad_pcb]
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2020-03-27 Squashed commit of the following:
    commit 0573e733ffc2a0f8f9404fb672cdf472d7d182e4
    Author: mike stedman <barbeque@users.noreply.github.com>
    Date: Fri Mar 27 07:56:41 2020 -0600
    Eat shit other me
    commit 68b1ea6bce640c772a96e1186761b76c8d888606
    Author: mike stedman <barbeque@users.noreply.github.com>
    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
    [ColecoVision Clone.kicad_pcb, ColecoVision Clone.sch]
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2020-04-01 Fix some global label warnings
    [ColecoVision Clone.kicad_pcb, ColecoVision Clone.sch]
2020-04-01 PLCC Z80 bodge
    [ColecoVision Clone.sch]
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2020-04-01 Attach U11 to power, add dedicated crystal for TMS
    [ColecoVision Clone.kicad_pcb, Power.sch, Video.sch]
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2020-04-01 Add DigiKey part number for 33pF clock caps
    [Video.sch]
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2020-06-09 Add test points, fix a gnarly trace
    [ColecoVision Clone.kicad_pcb, Power.sch]
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2020-06-10 Fix TMS9918 clock circuit
    [ColecoVision Clone.kicad_pcb, Video.sch]
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2020-06-12 Get rid of EXT_QUAD and clean up the reset line
    [ColecoVision Clone.kicad_pcb]
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2020-06-14 TODOs to fix the latest idiocy
    [ColecoVision Clone.sch]
2020-06-15 Apply all the bodges so far
    [ColecoVision Clone.kicad_pcb, ColecoVision Clone.sch, Expansion.sch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]
2020-06-15 Use '05 for the /WAIT inversion, not an '04 which would conflict with the sound chip
    [ColecoVision Clone.kicad_pcb, Power.sch]
2020-06-15 Output transistor fix
    [Video.sch]
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2020-06-18 Fix the callouts for the SRAM logic
    [Video.sch]
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2020-07-03 Fix silkscreen positions
    [ColecoVision Clone.kicad_pcb]
2021-09-22 Fix missing junction and bump version to 0.7
    [ColecoVision Clone.kicad_pcb, ColecoVision Clone.sch, Controllers.sch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]
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2021-10-26 Flip controller port #s
    [ColecoVision Clone.kicad_pcb, Controllers.sch]
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2021-10-26 Make the ground switching flipflop look better
    [ColecoVision Clone.sch, Controllers.sch]
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2021-11-04 Reinforcement hole near cartridge slot
    [ColecoVision Clone.kicad_pcb]
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2022-01-03 Squashed commit of the following:
    commit 92abf32cadf827114d19584acd122949932597b3
    Author: mike <barbeque@users.noreply.github.com>
    Date: Mon Jan 3 10:32:57 2022 -0700
    Routing complete for new controller port part
    commit b2f35945ec75921dc30cd07b50809f4682bd367a
    Author: mike <barbeque@users.noreply.github.com>
    Date: Mon Jan 3 10:19:43 2022 -0700
    Fix the stupid pin assignment
    commit 4990d3c33f922ec1addda2a0fcbaea749a56b64e
    Author: mike <barbeque@users.noreply.github.com>
    Date: Mon Jan 3 10:18:26 2022 -0700
    Checking numbering on controller port
    [ColecoVision Clone.kicad_pcb, Controllers.sch]
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2022-03-10 Replace 1k with 1.5k across the board to reduce BOM
    [ColecoVision Clone.kicad_pcb, Power.sch, Sound.sch]
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2022-04-06 Move C25 away from video port so it doesn't hit the connector
    [ColecoVision Clone.kicad_pcb]
2022-04-06 Send chips to other side so they don't interfere with cart slot
    [ColecoVision Clone.kicad_pcb]
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2022-04-20 Use TE AMP 5530843-2 cartridge slot, same as v0.6
    [ColecoVision Clone.sch]
2022-05-10 Finally added bodge jumper to defeat ICL7660 and pull down to ground
    [ColecoVision Clone.kicad_pcb, Power.sch]
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2024-04-19 Use solid connections for pours instead of spokes
    [ColecoVision Clone.kicad_pcb]
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2024-11-01 Known issue: power-on
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

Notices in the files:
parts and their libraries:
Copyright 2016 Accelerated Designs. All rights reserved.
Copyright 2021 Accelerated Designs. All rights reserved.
